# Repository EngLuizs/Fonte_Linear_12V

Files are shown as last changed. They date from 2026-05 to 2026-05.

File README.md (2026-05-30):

# FONTE LINEAR AJUSTÁVEL 12V 1A COM MONITORAMENTO

Projeto desenvolvido pela equipe **FLM System** utilizando ESP32, KiCad e PlatformIO para controle, monitoramento e interface web de uma fonte linear regulada ajustável.

---

# Descrição do Projeto

O projeto consiste em uma fonte linear ajustável de até 12V e 1A com:

- Monitoramento de tensão, corrente e potência
- Interface Web via ESP32
- Display LCD I2C 20x4
- Medição analógica calibrada
- Indicação visual por LED
- PCB dedicada desenvolvida no KiCad
- Controle e aquisição utilizando ESP32-WROOM-32E

O sistema disponibiliza os dados em tempo real tanto no display LCD quanto em uma página web hospedada diretamente pelo ESP32 em modo Access Point.

---

# Funcionalidades

- Leitura de tensão de saída
- Leitura de corrente utilizando resistor shunt
- Cálculo automático de potência
- Web Server integrado
- Interface Web responsiva
- Calibração de tensão e corrente
- LEDs indicadores de status
- Comunicação I2C com display LCD
- Sistema de proteção visual por sobrecorrente

---

# Hardware Utilizado

## Processador
- ESP32-WROOM-32E

## Reguladores
- LM7812
- LM2576
- LD1117

## Componentes principais
- LM358
- TIP120
- BC547
- LCD I2C 20x4
- Shunt 0.22Ω / 5W 
- Shunt 0,33Ω / 5W

---

# Estrutura do Projeto

```text
Firmware/       -> Código fonte do ESP32
Hardware/            -> Esquemáticos, PCB e Gerbers
Documentação/   -> Relatórios e documentação
Estrutura/      -> Estruturas e peças mecânicas
```

---

# Firmware

O firmware foi desenvolvido utilizando:

- Visual Studio Code
- PlatformIO
- Framework Arduino para ESP32

## Principais bibliotecas

- Arduino.h
- Wire.h
- LiquidCrystal_I2C
- WiFi.h
- WebServer.h

---

# Interface Web

O ESP32 opera em modo Access Point criando a rede:

```text
SSID: FLM_FTE12V
Senha: 11110000
```

Após conexão, o sistema disponibiliza:
- Página web embarcada
- Dados em JSON
- Monitoramento em tempo real

---

# Monitoramento

O sistema realiza:

- Média de amostras ADC
- Filtragem sincronizada em 60Hz
- Correção de offset
- Calibração linear de tensão e corrente

---

# PCB e Projeto Eletrônico

O projeto eletrônico foi desenvolvido no:

- KiCad

Incluindo:
- Esquemático completo
- PCB dedicada
- Gerbers de fabricação
- Instrumentação analógica
- Fonte linear regulada
- Conversores DC-DC auxiliares

---

# Organização de Versionamento

Este projeto utiliza:

- Git
- GitHub

Para:
- Controle de revisões
- Histórico de alterações
- Backup
- Versionamento de firmware e PCB

---

# Equipe

FLM System

---

# Versão Atual

```text
Versão Firmware: 0.02.01
Última Revisão: 01/05/2026
```

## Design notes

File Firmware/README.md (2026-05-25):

# 💻 Firmware - Fonte Linear Ajustável (FLM System)

Este diretório contém o código-fonte integral do microcontrolador **ESP32**, responsável pelo sistema de instrumentação inteligente, processamento digital de sinais (DSP) e telemetria remota da Fonte Linear Ajustável (12V / 1A).

O desenvolvimento foi realizado em **C++**, com gerenciamento de dependências e compilação otimizada pelo **PlatformIO** no ambiente Visual Studio Code.

---

## 🗂️ Arquitetura do Software

A arquitetura foi projetada para otimizar o uso da memória SRAM do microcontrolador, isolando a lógica de controle pesada da interface gráfica:

* 📄 **`main.cpp`**: O núcleo de controle. Gerencia periféricos (I2C, ADC, Wi-Fi), executa o ciclo de DSP, calibra as leituras e responde aos *endpoints* da API REST.
* 📄 **`html.h`**: Armazena o *front-end* completo (HTML, CSS e JavaScript Vanilla) diretamente na memória de programa do chip (`PROGMEM`), liberando a RAM para o processamento de rede.
* 📄 **`images.h` e `images.cpp`**: Recursos visuais convertidos em matrizes de bytes binários (*hex arrays*), evitando a necessidade de um sistema de arquivos (SPIFFS/LittleFS).

---

## 🧠 Processamento Digital de Sinais (DSP) e Calibração

O grande diferencial deste firmware é atuar como um instrumento de precisão, não confiando cegamente nas leituras brutas do ADC. Foram implementadas quatro camadas de tratamento matemático:

### 1. Filtro Passa-Baixa (Rejeição de 60Hz)
Para mitigar o ruído eletromagnético (EMI) e a oscilação (*ripple*) da fonte AC, a função `lerMedia()` coleta 60 amostras do ADC com um atraso cirúrgico de 277µs entre cada leitura. 
O tempo total de amostragem ($60 \times 277\mu s$) resulta em aproximadamente **16,6 milissegundos** — o equivalente exato a um ciclo completo da rede elétrica de 60Hz. Isso promove o cancelamento natural das harmônicas da rede.

### 2. Auto-Tara de Ruído Basal (Offset)
Amplificadores Operacionais possuem tensões de deslocamento intrínsecas. Durante o *boot*, o algoritmo executa `medirOffset()`, aferindo 200 amostras do canal de corrente com a fonte em repouso. Esse viés de hardware é armazenado e subtraído de todas as leituras futuras, garantindo que o zero absoluto seja real.

### 3. Regressão Linear de 2 Pontos
A não-linearidade do ADC do ESP32 foi corrigida via software aplicando a equação da reta ($y = ax + b$). O código compara tensões e correntes reais medidas por um instrumento de referência com as leituras brutas do ADC, calculando os coeficientes dinamicamente para gerar uma leitura perfeitamente calibrada.

### 4. Compensação de Carga (Voltage Drop)
Como o resistor *shunt* (0,22 Ω) está em série com o retorno (GND), ele gera uma queda de tensão que mascararia o valor entregue à carga. O firmware calcula ativamente a tensão dissipada pelo próprio *shunt* e a subtrai da medição global da fonte (`tensaoAtual = tensao - Vshunt_real`), exibindo apenas a tensão útil e real.

### 5. Supressão de Zona Morta (Zero Blanking)
Ruídos térmicos residuais que representem medições fantasmas inferiores a **90mA** são logicamente forçados a `0.000 A`, garantindo total estabilidade do display em momentos de circuito aberto.

---

## 📡 Servidor Web e Interface Gráfica

O ESP32 atua de forma autônoma como um *Soft Access Point* (SoftAP), gerando sua própria rede Wi-Fi (`SSID: FLM_FTE12V`). O roteamento foi desenhado no padrão REST:

* **`GET /`** : Transmite o Dashboard (Dashboard responsivo e sem recarregamento de página).
* **`GET /dados`** : Endpoint de telemetria. Retorna um **JSON** com as grandezas filtradas em tempo real. Exemplo:
  ```json
  {"v": 12.05, "i": 0.850, "p": 10.24}

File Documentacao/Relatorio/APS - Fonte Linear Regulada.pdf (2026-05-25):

UNIVERSIDADE PAULISTA CAMPUS RIBEIRÃO PRETO

ENGENHARIA ELÉTRICA (ELETRÔNICA)

Fonte Linear Regulada com Monitoramento Digital

Grupo: FLM System

Aluno: Luiz Henrique Luz Santos RA: F35CBF8

Aluno: Maycon Matheus Belchior da Silva RA: H7532E8

Aluno: Felipe de Oliveira Canjerano RA: G891988

Aluno: Marcos Vinicius Soares RA: F35CBA7

Aluno: Luís Gustavo Novaes R. Zanini RA: R9519I0

RIBEIRÃO PRETO

2026

LUIZ HENRIQUE LUZ SANTOS

FELIPE DE OLIVEIRA CANJERANO

MARCOS VINICIUS SOARES

MAYCON MATHEUS BELCHIOR DA SILVA

LUIS GUSTAVO NOVAES R

“FONTE LINEAR REGULADA COM MONITORAMENTO DIGITAL” 42A4 - APS - ATIVIDADES PRÁTICAS SUPERVISIONADAS

Aprovado(a) em: ______/______/______

BANCA EXAMINADORA

_________________________________

Prof. Matheus Kotaki

Universidade Paulista - UNIP

RIBEIRÃO PRETO

2026

RESUMO

Este relatório apresenta o desenvolvimento da Atividade Prática Supervisionada

(APS) da Engenharia Elétrica (Eletrônica) no primeiro semestre letivo de 2026. O

objetivo principal do trabalho consiste na construção de uma fonte de alimentação linear

12 volts ajustável e na realização de testes experimentais no projeto. Essa atividade tem

o intuito de colaborar diretamente no aprendizado do curso integrando realizações

práticas com o conhecimento teórico apresentado ao longo do quinto semestre do curso.

Nas seguintes etapas, o relatório apresenta seções importantes que ajudam na

compreensão e validação do trabalho, como a fundamentação teórica dos conceitos

principais do projeto, método de construção adotado, materiais utilizados, cálculos

teóricos e comparações com valores medidos, confirmação do objetivo do projeto, uma

conclusão do trabalho detalhando as dificuldades e opiniões obtidas pelo grupo e uma

série de testes essenciais para validar o funcionamento e garantir a segurança na utilização

da fonte linear.

ABSTRACT

This report presents the development of the Supervised Practical Activity (APS)

in Electrical Engineering (Electronics) during the first semester of 2026. The main

objective of the work is to construct a 12 volt adjustable linear power supply and to carry

out experimental tests of the project. This activity aims to contribute directly to the

learning process of the discipline, integrating practical achievements with the theoretical

knowledge presented throughout the fifth semester. In the following stages, the report

presents important sections that aid in the understanding and validation of the work, such

as the theoretical foundation of the main concepts of the project, the construction method

adopted, the materials used, the theoretical calculations and comparisons with measured

values, the confirmation of the project's objective, a conclusion detailing the difficulties

and opinions obtained by the group, and a series of essential tests to validate the operation

and ensure the safety in the use of the linear power supply.

## Sumário

## Tabelas

Tabela 1 - Comparação das medições de tensão | 30

## Equações

Equação 1 – Tensão de ondulação na entrada do regulador | 23
Equação 2 – Corrente no diodo Zener | 23
Equação 3 – Potência dissipada no resistor | 23
Equação 4 – Tensão máxima na saída | 23
Equação 5 – Resistencia no resistor de proteção | 23
Equação 6 – Limite da corrente para proteção do circuito | 23
Equação 7 – Resistencia no resistor de leitura da corrente de referência | 23
Equação 8 – Leitura da tensão correlacionada a corrente de referência | 24
Equação 9 – Potência dissipada (LM7812) | 24
Equação 10 – Ondulação de corrente no indutor (LM2576) | 24
Equação 11 – Valor da corrente de pico no indutor | 24
Equação 12 – Potência dissipada (LD1117) | 24
Equação 13 – Divisor de tensão para leitura de tensão através do ESP32 | 24
Equação 14 – Leitura da tensão no ESP32 | 24
Equação 15 – Realimentação no U2A | 24
Equação 16 – Ganho de tensão no U2A | 24
Equação 17 – Sinal final da corrente no U2A | 24
Equação 18 – Corrente no LED vermelho | 25
Equação 19 – Corrente no LED verde | 25
Equação 20 - Erro do sistema de proteção da fonte | 33

## Figuras

### 1 Introdução

Uma fonte de tensão ajustável é um equipamento muito utilizado na área eletrônica, em

trabalho, cursos e graduações. A fonte é um objeto que, quando energizado em 127/220 V, pode

transformar essa energia de alternada para contínua. Sua funcionalidade consiste em energizar

circuitos através de pontas de prova conectadas.

Geralmente as pessoas que precisam utilizar a fonte de tensão, apenas conectam ela em

alguma tomada qualquer, fazem ajustes na tensão de saída necessária e a utilizam, porém, é

importante para seus usuários que entendam como ela funciona.

O que há dentro de uma fonte de tensão ajustável? Como funciona o sistema dentro de

uma fonte? Quais circuitos são necessários para gerar uma tensão contínua na saída da fonte?

Essas perguntas podem ser respondidas criando a sua própria fonte de tensão ajustável.

A Atividade Prática Supervisionada do quinto semestre do curso Engenharia Elétrica

(Eletrônica) da UNIP, consiste em realizar a montagem de uma fonte de tensão ajustável

completa, com a ideia de ajudar os alunos a entender como funciona o equipamento que é muito

utilizado pelos próprios estudantes.

### 1.1 Objetivo

O projeto consiste em realizar a montagem de uma fonte de tensão linear ajustável. Essa

fonte precisa de uma tensão de saída ajustável de 0 ~ 12 V ou mais, uma corrente máxima maior

ou igual a 1 A, alimentação a partir da rede elétrica e uma saída estabilizada. Alguns requisitos

também são obrigatórios, como o uso de um retificador de diodos, capacitor de filtragem,

referência de tensão, transistores na função de regulador, ajuste manual da tensão de saída

através de potenciômetros e o circuito deve permitir o controle contínuo, operação em regime

linear e estabilidade sob cargas.

Além desses requisitos, uma etapa importante que os alunos devem se atentar é a

proteção contra sobrecorrentes, o grupo deve usar componentes discretos como o resistor shunt,

justificar seu funcionamento e demonstrar a atuação na prática, além de que o monitoramento

da fonte deve ser digital através de um microcontrolador de forma coerente e que não

comprometa o funcionamento da fonte.

Após a montagem da fonte, os alunos têm como objetivo realizar testes no

funcionamento da fonte como a regulamentação de tensão, variação de carga, comparação de medição e testes na sobrecarga, e também realizar um relatório técnico explicando o passo a

passo da construção do projeto.

### 2 Fundamentação Teórica

### 2.1 Retificação e Filtragem

Para a realização da retificação e filtragem precisamos entender o conceito de diodos e

capacitores.

De acordo com o livro “Dispositivos eletrônicos e teoria dos circuitos” de Robert L.

Boylestad e Louis Nashelsky (BOYLESTAD E NASHELSKY), os diodos são semicondutores

com a funcionalidade de conduzir corrente em somente um sentido e agir como um circuito

aberto para qualquer tentativa de estabelecer corrente no sentido oposto.

Os diodos são feitos de silício e germânio e possuem dois terminais, o ânodo e o cátodo.

Quando o ânodo é energizado na tensão positiva, e o cátodo no negativo, obtemos a polarização

direta, nessa polarização o diodo trabalha conduzindo a carga no circuito e recebe uma queda

de tensão de 0,7 V para os diodos de silício, que são os mais comuns.

Quando o diodo é polarizado inversamente da polarização direta, obtemos a polarização

reversa, o diodo trabalha como um circuito aberto, pois não conduz carga no circuito.

Segundo o livro “Análise de Circuitos Elétricos com aplicações” de Matthew N. O.

Sadiku, Sarhan M. Musa e Charles K. Alexander (SADIKU, MUSA E ALEXANDER), os

capacitores são componentes eletrônicos que armazenam energia para que seja recuperada em

um momento posterior. Esse componente se opõe à variação de tensão, bloqueia passagem de

corrente elétrica contínua e armazena energia, se comportando como um filtro de tensão, e

possuem dielétricos de cerâmica, mica, poliéster, papel ou ar.

Circuitos retificadores são circuitos eletrônicos que convertem corrente alternada para

corrente contínua através de uma combinação de diodos. O mais eficiente é o circuito retificador

de onda completa, utilizando uma ponte de quatro diodos, dois diodos da ponte conduzem por

vez, aproveitando o semiciclo positivo e negativo da onda, gerando mais estabilidade da onda

na saída do circuito.

O capacitor serve para filtrar a tensão que sai do circuito, ele se enche até o pico e

descarrega de forma suave na carga do circuito, fazendo a tensão de saída ter poucas oscilações.

### 2.2 Regulação Linear

Para a realização da Regulação linear precisamos entender o conceito de diodo Zener e

Transistor na configuração Coletor-Comum.

Diferentemente de um diodo comum, o diodo Zener trabalha polarizado inversamente.

Quando polarizado diretamente, ele trabalha como um diodo comum, porém, quando

polarizado reversamente, mantém uma tensão constante de acordo com sua tensão de ruptura.

Para ativar o diodo Zener, a tensão no cátodo do diodo precisa atingir a tensão de ruptura

do componente, após atingir a tensão de ruptura do diodo, qualquer oscilação ou variação de

tensão que passar por ele não alterará na tensão de saída, pois sua função consiste em manter

uma tensão fixa nos terminais. O diodo Zener é muito utilizado em circuitos reguladores para

manter uma tensão fixa, utilizando também um resistor de carga.

De acordo com Boylestad e Nashelsky, o transistor é um dispositivo de silício

semicondutor que consiste em duas camadas de material do tipo N e uma do tipo P ou vice

versa. Sua função consiste em amplificar ou controlar o fluxo da corrente em um circuito, este

dispositivo possui três terminais: base, coletor e emissor.

O transistor na configuração Coletor-Comum possui alto valor de impedância de entrada

e baixo valor de impedância de saída, sendo assim, na região ativa esse componente trabalha

como um regulador, variando a impedância dentro do próprio componente. Essa configuração

de transistor consegue manter a tensão de saída proporcional à tensão de entrada (base) do

componente.

O circuito regulador linear utiliza do transistor e diodo Zener para estabilizar a carga

que vem do circuito retificador. A tensão da base do transistor é estabilizada pelo diodo Zener

e ajustada através de um potenciômetro ou divisor de tensão, estabilizando e controlando toda

a tensão de saída. Desse modo, o diodo Zener fixa um valor constante para tensão da base,

através do potenciômetro ou divisor a tensão se torna ajustável, a tensão entra na base do

transistor, e na configuração coletor-comum, o transistor trabalha como uma resistência

flexível.

### 2.3 Proteção Contra Sobrecorrente

Na realização de um circuito de proteção contra sobrecorrente, precisamos entender o

conceito do Resistor Shunt e sobre o Transistor como chave.

O resistor Shunt é um resistor com baixa resistência utilizado para medir correntes em

circuitos e proteger circuitos juntamente com um transistor como chave. Por ter baixa resistência, a queda de tensão nesse resistor é proporcional a corrente do circuito, vemos através

da lei de ohm (V = R x I).

Já o transistor como chave atua de uma forma um pouco diferente. Os transistores como

chave trabalham em duas regiões, a de corte e saturação. O transistor fica na região de corte

quando não circula corrente na base, bloqueando toda a circulação de carga que passar por ele,

na região de saturação o transistor circula corrente em sua base, permitindo que a corrente que

circula do coletor para o emissor flua normalmente. Dessa forma, o transistor como chave atua

como um interruptor que ativa e desativa a circulação de corrente no circuito para proteger.

O circuito de proteção contra sobrecorrente consiste em manter o resistor Shunt em série

com a saída do circuito e conectada na base do transistor como chave. Quando a corrente está

abaixo do limite permitido e estipulado pelo circuito, o transistor permanece na região de corte

(desligado) pois não há corrente circulando em sua base. Quando a corrente ultrapassa o limite

estipulado, a queda de tensão no resistor Shunt aumenta, fazendo assim o transistor entrar na

região de saturação (ligado). Quando o transistor como chave está saturado, a corrente

indesejada é desviada protegendo o circuito completo.

### 2.4 Sistema Microcontrolado

Sistemas microcontrolados integram memorias, processadores, entradas e saídas em um

circuito integrado. Para a fonte linear ajustável, foi utilizado o microcontrolador ESP32, um

componente de 32 bits dual-core.

O ESP32 é um pouco diferente dos outros microcontroladores de oito bits, pois opera

com frequências altas e possui conectividade wireless. Para a realização de montagem de fontes

de bancada, o ESP32 geralmente é o mais escolhido pela sua quantidade de pinos de

entrada/saída e pela especialização na conversão de sinais analógicos em digital.

Neste projeto, existem valores que são sinais analógicos, como a tensão sobre a carga,

por isso, é necessário a digitalização desses sinais para que o processor interno do ESP32

consiga interpretá-los, função realizada pelo ADC. O Conversor Analógico Digital trabalha em

três etapas: Na amostragem, o ADC captura os valores analógicos. Na quantização, ele mapeia

o valor analógico em um nível de tensão que corresponde a uma escala determinada pela

resolução do circuito. E na codificação, ele converte o sinal em uma palavra binaria que é lida

pelo firmware.

Um dos problemas do microcontrolador são as restrições nas entradas que só suportam

no máximo 3,3 V, sinal de alta potência não pode ser conectado ao microcontrolador. Esse problema é resolvido com os Amplificadores Operacionais, esses amplificadores são circuitos

integrados analógicos com alto ganho nas entradas.

Para exibir as variáveis medidas sem muitos pinos do microcontrolador, é importante

adotar o protocolo de comunicação I2C, esse protocolo da Philips utiliza uma topologia baseada

em apenas dois condutores ativos. Serial Data é a linha responsável pela transferência serial de

dados nos dispositivos e o Serial Clock é responsável pelo sinal que gera sincronismo nos

dispositivos (VICTOR VISION, 2022).

### 3 Materiais e Métodos

### 3.1 Projeto do Circuito

O projeto elétrico foi concebido sob uma topologia híbrida, integrando um estágio

analógico robusto, dedicado à regulação linear de potência, e um estágio digital de precisão,

responsável pela telemetria e conectividade. O escopo principal do projeto é garantir o

fornecimento de uma tensão contínua ajustável de 0 a 12V com capacidade de corrente de até

1A, mantendo a estabilidade da tensão de saída e a proteção ativa do hardware contra falhas na

carga.

Para otimizar o desenvolvimento, isolar ruídos e facilitar a análise de falhas, a

arquitetura do hardware foi dividida em cinco módulos funcionais inter-relacionados:

Módulo de Retificação e Filtragem: Responsável por receber a tensão alternada (AC)

proveniente do transformador, realizar a retificação em onda completa através de uma ponte de

diodos e atenuar a oscilação (Ripple) utilizando um banco de capacitores eletrolíticos de alta

capacitância, entregando o barramento DC principal (+18V) ao sistema.

Módulo de Regulação e Potência: O núcleo de controle analógico da fonte. Utiliza a

configuração Darlington para modular a tensão de saída conforme o ajuste do usuário no

potenciômetro e o referencial do diodo Zener.

Módulo de Proteção Ativa: Circuito de segurança em malha fechada composto por

resistores de limitação e um transistor. Este bloco atua drenando a corrente de base do transistor

de potência caso a corrente total do sistema ultrapasse o limite seguro de projeto, cortando a

saída imediatamente.

Módulo de Instrumentação Analógica: Estágio de condicionamento de sinal. Utiliza

divisores de tensão resistivos e um resistor Shunt no caminho de retorno (GND). As quedas de

tensão geradas são tratadas por Amplificadores Operacionais, adequando as altas tensões da

fonte para os níveis lógicos seguros de leitura do microcontrolador (0 a 1.1V).

Módulo de Processamento e Conectividade: Centrado no microcontrolador ESP32.

Este bloco opera de forma passiva em relação à potência da fonte, realizando a conversão

analógico-digital (ADC) dos sinais de instrumentação, o tratamento matemático via software e

a disponibilização dos dados no display LCD e no Servidor Web Wi-Fi.

Esta modularização garante que a lógica de controle digital opere de maneira segura,

minimizando interferências provenientes do chaveamento e do calor gerado pelas cargas de alta

potência.

### 3.2 Montagem Experimental

Após inúmeras reuniões e apresentações de ideias entre o grupo, a fonte finalmente tinha

um começo no digital, com auxílio do Software KiCad foi desenvolvida uma primeira amostra

de um esquemático da possível fonte. Com todos os testes, análises, modificações e quase

certeza que o projeto estava apto, a realização da criação da PCB da fonte foi iniciada.

A confecção da Placa de Circuito Impresso (PCB) de dupla face foi realizada em etapas

sequenciais, unindo usinagem, transferência térmica e processos fotoquímicos. O fluxo de

fabricação seguiu as seguintes fases:

- Usinagem e Transferência de Layout: Inicialmente, a placa de fenolite foi

dimensionada e cortada com o auxílio de uma fresadora CNC (Figura 1). Em seguida,

o layout do circuito foi aplicado de forma alinhada nas faces inferior (Bottom Layer) e

superior (Top Layer) através do método de transferência térmica (Figuras 2 e 3).

- Corrosão Química: Para a remoção do cobre não utilizado, a placa foi submetida a um

banho químico utilizando percloreto de ferro (Figura 4). Esse processo garantiu o

isolamento perfeito das trilhas protegidas pelo polímero do toner, resultando nas

camadas limpas e corroídas (Figuras 5 e 6).

- Aplicação da Máscara de Solda (Solder Mask): Após a limpeza, a PCB recebeu a

aplicação de uma tinta fotossensível protetora (Figura 7). Para garantir que apenas as

ilhas de soldagem (pads) ficassem expostas, utilizou-se um fotolito impresso em papel

transparente alinhado milimetricamente sobre a placa (Figura 8). A secagem e

polimerização da resina foram realizadas mediante exposição controlada à luz

ultravioleta (UV) durante um tempo de aproximadamente 5 à 10 minutos (Figura 9),

finalizando o processo de cura em ambas as faces (Figuras 10 e 11).

- Acabamento Final: O uso da máscara UV teve como objetivo proteger as trilhas de

cobre contra a oxidação natural, prevenir curtos-circuitos acidentais durante a futura

fixação dos componentes com estanho e conferir um acabamento estético e profissional

às faces inferior e superior da placa finalizada (Figuras 12 e 13).

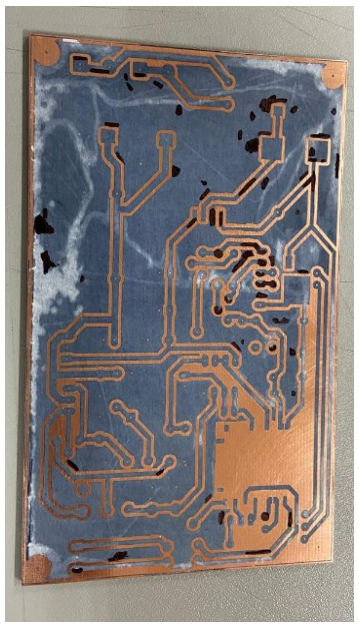
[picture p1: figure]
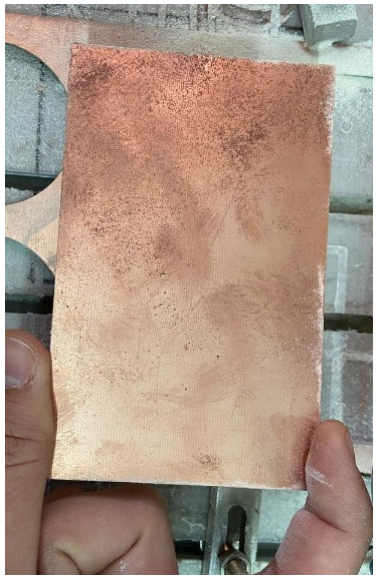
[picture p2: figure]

Figura 1 – Corte da placa fenolite na Fresa CNC. Figura 2 – Transferência térmica do Bottom Layer.

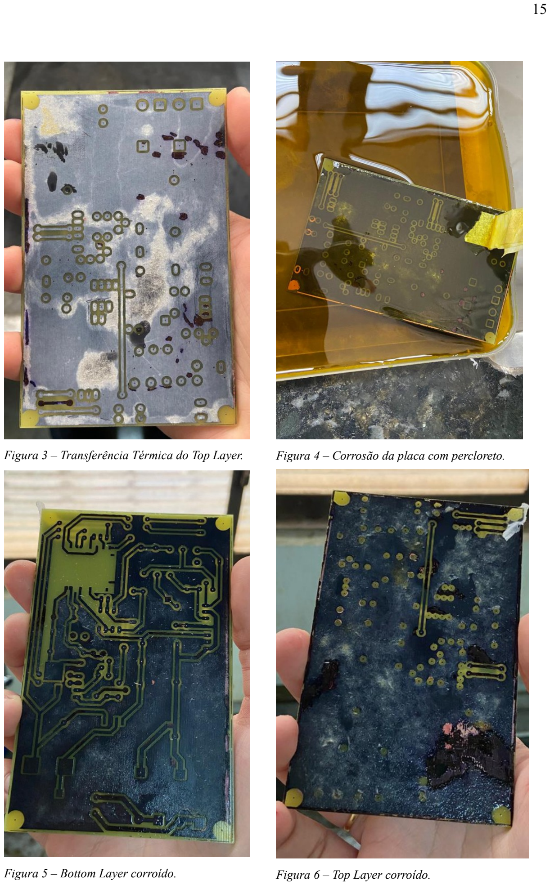
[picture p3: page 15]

Figura 3 – Transferência Térmica do Top Layer. | Figura 4 – Corrosão da placa com percloreto.
Figura 5 – Bottom Layer corroído. | Figura 6 – Top Layer corroído.

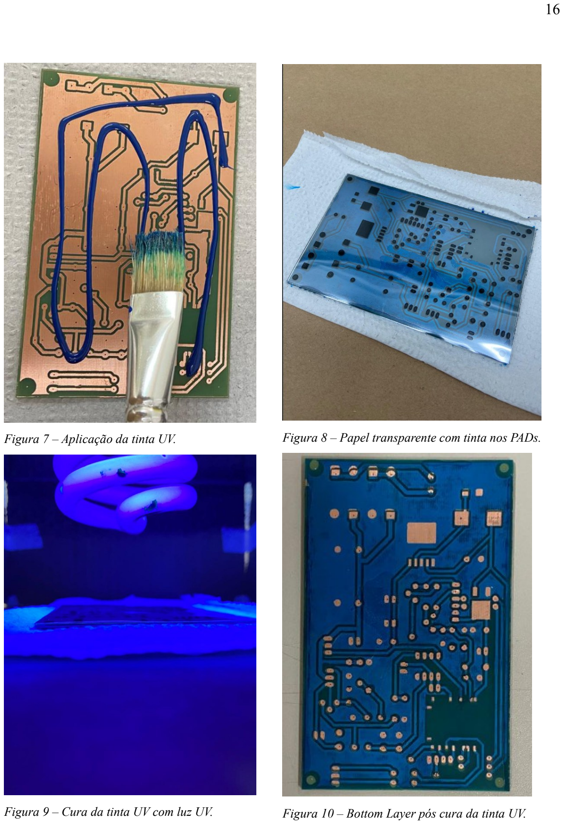
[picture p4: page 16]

Figura 7 – Aplicação da tinta UV. | Figura 8 – Papel transparente com tinta nos PADs.
Figura 9 – Cura da tinta UV com luz UV. | Figura 10 – Bottom Layer pós cura da tinta UV.

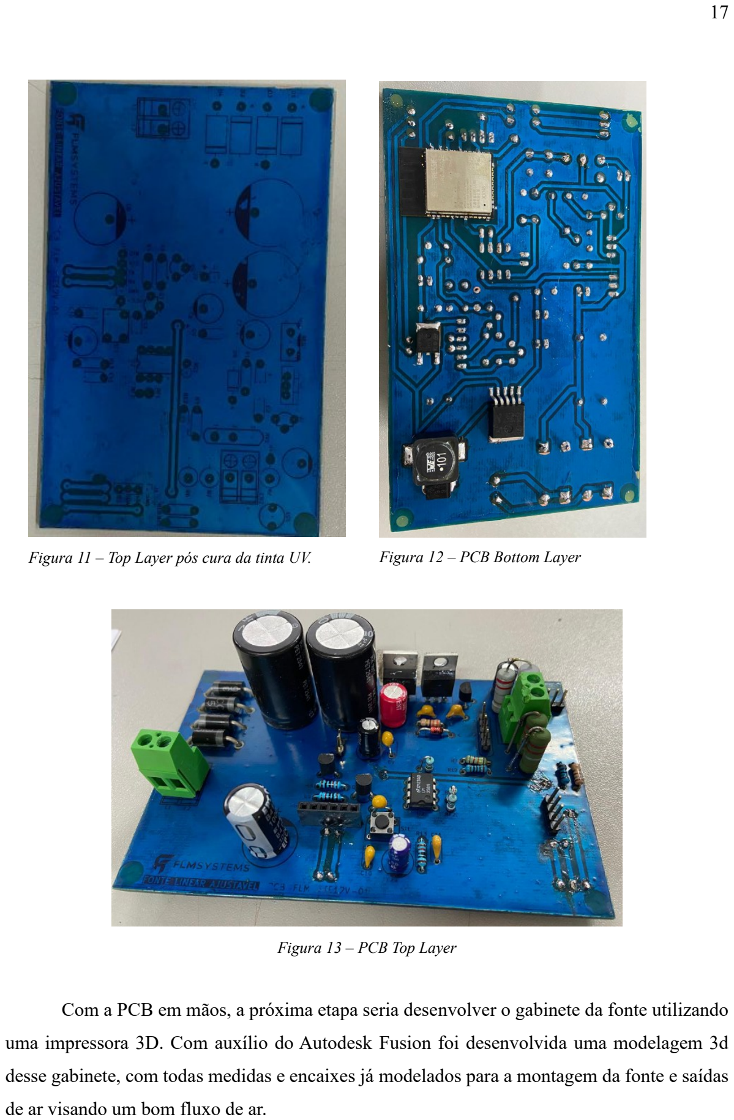
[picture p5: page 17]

Figura 11 – Top Layer pós cura da tinta UV. | Figura 12 – PCB Bottom Layer

Figura 13 – PCB Top Layer

Com a PCB em mãos, a próxima etapa seria desenvolver o gabinete da fonte utilizando

uma impressora 3D. Com auxílio do Autodesk Fusion foi desenvolvida uma modelagem 3d

desse gabinete, com todas medidas e encaixes já modelados para a montagem da fonte e saídas

de ar visando um bom fluxo de ar.

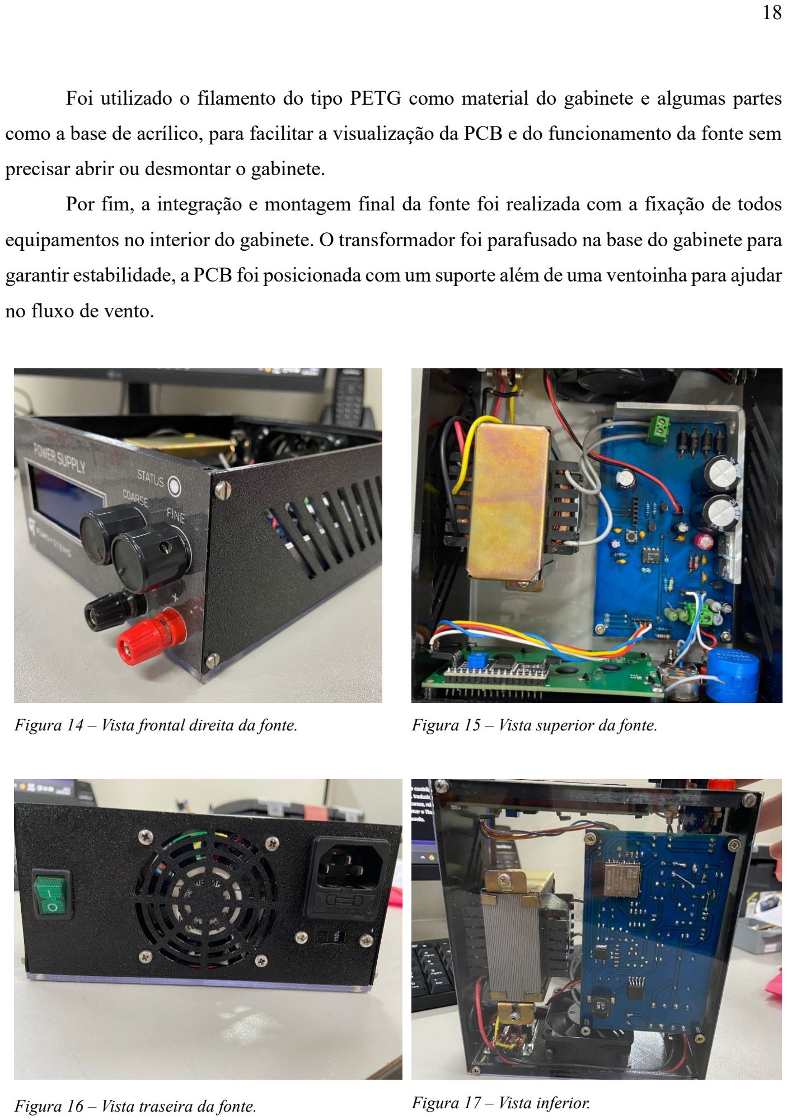
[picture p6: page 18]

Foi utilizado o filamento do tipo PETG como material do gabinete e algumas partes

como a base de acrílico, para facilitar a visualização da PCB e do funcionamento da fonte sem

precisar abrir ou desmontar o gabinete.

Por fim, a integração e montagem final da fonte foi realizada com a fixação de todos

equipamentos no interior do gabinete. O transformador foi parafusado na base do gabinete para

garantir estabilidade, a PCB foi posicionada com um suporte além de uma ventoinha para ajudar

no fluxo de vento.

Figura 14 – Vista frontal direita da fonte. | Figura 15 – Vista superior da fonte.
Figura 16 – Vista traseira da fonte. | Figura 17 – Vista inferior.

### 3.3 Esquemático

O diagrama esquemático representa a modelagem lógica e elétrica global da fonte linear

ajustável, mapeando as interconexões fundamentais entre os blocos de potência, regulação,

segurança e o sistema microcontrolado baseado no ESP32. Este documento técnico estabelece

a topologia exata das trilhas, barramentos de comunicação (I2C), redes de distribuição de tensão

(+18V, +12V, +5V, +3.3V) e o correto acoplamento dos componentes discretos e circuitos

integrados.

Para assegurar o rigor técnico e preservar a perfeita legibilidade das trilhas, pinagens e

identificadores (designators) de componentes, os quais sofreriam perda de resolução se

reduzidos às margens normativas deste relatório, os diagramas técnicos completos foram

exportados diretamente do software de automação de design eletrônico (KiCad) e

disponibilizados em alta definição.

A documentação oficial de hardware encontra-se indexada e versionada no repositório

público da equipe no GitHub através do endereço eletrônico: PCB - Layout, (https://github.com/EngLuizs/Fonte_Linear_12V/tree/main/PCB/PDF) contendo os

seguintes arquivos:

- FLM-FTE-SCH-01.pdf: Diagrama esquemático completo do circuito, detalhando as

conexões elétricas e pinagens de controle.

- FLM-FTE-PCB-01.pdf: Desenho técnico de posicionamento de componentes e

roteamento das camadas física superior (Top) e inferior (Bottom).

- FLM-FTE-PCB-FAB-01.pdf: Arquivo consolidado com as máscaras de solda, furação

e guias de gabarito para os processos de transferência térmica e fabricação da placa.

- FLM-FTE-PCB-3D-01.pdf: Modelagem tridimensional da placa montada (PCBA),

permitindo a visualização espacial dos componentes, verificação de folgas mecânicas

(clearances) e validação para o encapsulamento no gabinete impresso.

### 3.4 Funcionamento dos componentes

Diodos Retificadores (1N5406) são posicionados em forma de ponte que fazem esses

semicondutores conduzirem corrente em pares durante dois semi-ciclos (positivo e negativo), fazendo assim, a corrente alternada que vem do transformador ser convertida em corrente

contínua.

Capacitores de filtro (4700 µF) atuam como filtro, eles guardam a energia nos pontos

de pico das ondas e descarregam de forma suave reduzindo a oscilação da tensão, entregando

uma tensão mais regular e estável.

Diodo Zener (1N4744A) trabalhando na região de ruptura inversa, esse diodo consegue

fixar a tensão de referência que chega no potenciômetro, independe das oscilações que tiverem

na entrada do circuito, a tensão no diodo Zener não oscila.

Resistor de polarização (330 Ω) serve para limitar a corrente que circula no diodo

Zener, evitando sobreaquecimento ele permite o diodo Zener trabalhar na região ideal com

segurança e polariza o diodo.

Potenciômetro (11k Ω) atua como um divisor de tensão ajustável, ele posicionado em

paralelo com o diodo Zener e conectado na base do transistor de potência, pode ajustar a tensão

de saída da fonte conforme o giro do seu eixo.

Transistor de Potência (TIP120) é o principal regulador do circuito pois oferece um

ganho alto de corrente, ele recebe uma corrente baixa em sua base que serve como controle para

uma corrente maior que vai para a carga.

Transistor de Proteção (BC547) age como uma chave de proteção no circuito, esse

transistor monitora a queda de tensão nos resistores de proteção, quando essa queda passar de

0,7 V ele desvia a corrente de sua base diretamente ao GND, desta forma, protegendo o circuito

de um curto-circuito ou sobrecorrente.

Resistores de Proteção (0,33 Ω; 0,22 Ω) em série na saída da fonte, servem para

converter a corrente da saída em tensão, sendo assim, fazendo o transistor de proteção conseguir

monitorar a segurança do circuito.

Resistores Shunt (0,22 Ω) na linha de retorno conseguem gerar uma queda de tensão

proporcional à corrente consumida no circuito, sendo essencial para o sistema de medição da

fonte.

O capacitor (0,1 µF) serve também como filtro, porém, especificamente para a tensão

de referência no diodo Zener e potenciômetro.

O capacitor (100µF) atua como um filtro focado na estabilidade da fonte, suavizando

as transições que acontece no circuito.

Regulador Linear (LM7812) Recebe 18 V da filtragem do circuito e reduz para 12 V

com sua regulação interna.

Regulador Chaveado (LM2576D2TR4–5G) é um circuito integrado conversor DC–

DC, que no circuito reduz a tensão de 12 V para 5 V ligando e desligando internamente.

Diodo Schottky (SS36) fornece um caminho em que a corrente armazenada no indutor

continue fluindo evitando picos de alta tensão quando o regulador chaveado está fechado.

Indutor (100µH) armazena energia em campo magnético quando o regulador está

fechado e libera a energia quando o regulador abre.

Capacitor (1000µF) junto com o indutor forma um filtro passa–baixas que transforma

a pulsação da onda em uma tensão contínua de 5 V.

Regulador LDO (LD1117DT33TR) tem uma baixa queda de tensão, recebe 5 V estável

e fixa uma saída de 3,3 V para alimentar o microcontrolador.

Capacitores de Desacoplamento (0,1; 100; 0,1; 100; 0,1; 10 µF) filtram os ruídos da

rede ou chaveamento, gerando estabilidade nas entradas e saídas dos circuitos integrados.

Microcontrolador (ESP32) executa o firmware do projeto, realiza todas leituras e

cálculos de monitoramento, gerencia as proteções do circuito e envia todas informações

necessárias para o display.

Amplificadores Operacionais U2B, U2A (LM358N) são circuitos amplificadores, o

U2B isola o divisor de tensão da saída da fonte para garantir a não interferência da leitura com

o valor de saída. Já o U2A multiplica por 4 o sinal do resistor Shunt, transformando esse valor

em legível para o ESP32 conseguir medir a corrente.

Resistores no Divisor de Tensão (14k Ω, 1k Ω) reduzem a tensão máxima para uma

faixa segura que permite a leitura pelo pino analógico do ESP32

Transistores (BC547) funcionam como chaves digitais automáticas comandadas por

sinais digitais que colocam o ESP32 em modo gravação.

O Botão ST1 possibilita resetar o microcontrolador, o resistor 10k Ω mantém o pino reset

em nível alto e o capacitor 0,1 µF elimina os ruídos desse circuito.

LED Bicolor com resistores (180 Ω, 150 Ω) age como indicador visual do status da

fonte, os resistores limitam a corrente dos LEDs.

### 3.4.1 Lista de Materiais (B.O.M. - Bill of Materials)

Com o intuito de garantir a total reprodutibilidade do hardware e documentar de forma

rigorosa todos os insumos utilizados, a Lista de Materiais (B.O.M.) da fonte linear regulada foi

consolidada em uma planilha digital detalhada.

Para manter a clareza e a formatação enxuta deste relatório, o documento completo em

formato Excel (.xlsx) encontra-se hospedado e versionado no repositório público da equipe no

GitHub. A lista de especificações pode ser acessada através do seguinte endereço eletrônico:

Lista de Materiais - B.O.M. (https://github.com/EngLuizs/Fonte_Linear_12V/tree/main/PCB/BOM)

A estrutura da listagem foi desenvolvida em total consonância com o projeto modelado

no software de automação de design eletrônico KiCad. Para cada item listado na planilha, o

avaliador encontrará as seguintes especificações técnicas:

- Designator: A referência unívoca e identificadora do componente no diagrama

esquemático (ex: R1, C1, U1);

- Valor / Modelo: A especificação nominal ou o modelo comercial do componente;
- Footprint (Encapsulamento): O padrão de desenho físico e dimensional adotado para

a furação, posicionamento e soldagem dos terminais na PCB;

- Quantidade (Qtd.): O volume total de unidades necessárias para a montagem de uma

placa.

### 3.5 Cálculos

∆Vripple =

Imax
ℱ × C

Equação 1 – Tensão de ondulação na entrada do regulador

Iz =

Vin − Vz
R1

→

18 V − 15 V
330 Ω

= 9 mA

Equação 2 – Corrente no diodo Zener

Pr =

(Vin − Vz)²
R1

→

(18 V − 15 V)²
330 Ω

= 27 mW

Equação 3 – Potência dissipada no resistor

Vout = Vbase (TIP120) − Vbe (TIP120) → 15 V − 1,4 V = 13,6 V

Equação 4 – Tensão máxima na saída

Rproteção = R2 + R4 → 0,33 Ω + 0,22 Ω = 0,55 Ω

Equação 5 – Resistencia no resistor de proteção

Ilimite =

Vbe (BC547)

Rproteção

→

0,7 V
0,55Ω ≅ 1,27 A

Equação 6 – Limite da corrente para proteção do circuito

Rref = R6 → 0,22 Ω

Equação 7 – Resistencia no resistor de leitura da corrente de referência

Vsℎunt = I × Rref

Equação 8 – Leitura da tensão correlacionada a corrente de referência

Pd

(LM7812) = Vin − Vout × Iout → 18V − 12V × 0,5 A = 3 W

Equação 9 – Potência dissipada (LM7812)

∆Il (LM2576) =

Vin − Vout × Vout
Vin × ℱ × L

→

12 V − 5 V × 5 V
12 V × 52 kHz × 100µH

= 0,56 A

Equação 10 – Ondulação de corrente no indutor (LM2576)

Ipico = Iout +

∆Il
2

→ 1 A +

0,56 A
2

= 1,28 A

Equação 11 – Valor da corrente de pico no indutor

Pd

(LD1117) = Vin − Vout × Iout → 5 V − 3,3 V × 0,2 A = 0,34 W

Equação 12 – Potência dissipada (LD1117)

V(U2B) = Vout ×

R12
R3 + R12

→ 15 V ×

1k Ω
14k Ω + 1k Ω

= 1 V

Equação 13 – Divisor de tensão para leitura de tensão através do ESP32

Ler_V = VU2B

Equação 14 – Leitura da tensão no ESP32

RF = RF1 + RF2 → 15k Ω + 15k Ω = 30k Ω

Equação 15 – Realimentação no U2A

GU2A = 1 +

RF

RG1

→ 1 +

30k Ω
10k Ω

= 4

Equação 16 – Ganho de tensão no U2A

Ler_I = GU2A × Ler_Iref (Icarga × 0,22 Ω) → 4 x 1,1A x 0,22Ω = 0,968 V

Equação 17 – Sinal final da corrente no U2A

ILEDRED =

Vin − VD
R10

→

3,3 V − 2 V
180 Ω

= 7,22 mA

Equação 18 – Corrente no LED vermelho

ILEDgreen =

Vin − VD
R11

→

3,3 V − 2 V
150 Ω

= 8,66 mA

Equação 19 – Corrente no LED verde

### 3.6 Firmware

O firmware do sistema foi integralmente desenvolvido sob o ecossistema de código

aberto utilizando a linguagem C++ integrada ao framework Arduino. Como ambiente de

desenvolvimento (IDE), adotou-se o Visual Studio Code (VS Code) em conjunto com a

extensão PlatformIO. Esta escolha justifica-se pela robustez no gerenciamento de bibliotecas,

compilação otimizada para o processador de arquitetura Xtensa de 32 bits do ESP32 e suporte

avançado a sistemas de versionamento.

A arquitetura do software foi estruturada de forma modular para otimizar o uso de

memória do microcontrolador, dividindo-se em três arquivos principais:

- Código Principal (src/main.cpp): Responsável pelo controle de baixo nível,

inicialização de periféricos, execução dos filtros digitais e gerenciamento das

requisições do servidor.

- Interface Web (include/html.h): Arquivo de cabeçalho que armazena a estrutura do

front-end (HTML, CSS e JavaScript) na memória de programa do chip (PROGMEM),

evitando o consumo da memória RAM (SRAM) dinâmica.

- Recursos Visuais (include/images.h): Armazena as imagens de interface convertidas

em matrizes de bytes binários (hex arrays) para transmissão direta via rede.

### 3.6.1 Bibliotecas e Periféricos

Para a operação integrada dos componentes e protocolos de comunicação, o firmware

incorpora as seguintes bibliotecas nativas e externas:

- Arduino.h: Fornece a API base para controle dos pinos de Entrada/Saída (GPIO) e

temporizadores do chip.

- Wire.h: Gerencia o barramento de comunicação serial síncrona I2C nos pinos

customizados (SDA: GPIO 16, SCL: GPIO 19).

- LiquidCrystal_I2C.h: Controla o display LCD de 20 colunas por 4 linhas,

encapsulando os comandos de escrita e posicionamento de cursor via I2C.

- WiFi.h: Configura o modem de rádio do ESP32 para operar estritamente em modo Soft

Access Point (SoftAP), gerando uma rede local criptografada sem a necessidade de um

roteador externo.

- WebServer.h: Instancia um servidor HTTP escutando na porta padrão 80, encarregado

de processar os métodos de requisição dos clientes conectados.

### 3.6.2 Infraestrutura de Rede e Endpoints HTTP (API JSON)

O ESP32 atua simultaneamente como ponto de acesso Wi-Fi (SSID: "FLM_FTE12V")

e servidor de aplicação. O roteamento de dados do servidor web foi projetado sob o modelo

arquitetural REST, expondo endpoints específicos mapeados por meio de funções lambda:

1. Rota Raiz (/): Quando o usuário acessa o endereço IP da fonte, o servidor dispara uma

resposta HTTP com código de status 200 (OK), transmitindo o documento

INDEX_HTML em formato de texto e hipertexto.

2. Rota de Telemetria (/dados): Este endpoint expõe os dados brutos da fonte em tempo

real. Ele encapsula as variáveis globais de medição dinamicamente e as envia

formatadas como uma string em padrão JSON (JavaScript Object Notation), conforme

a estrutura abaixo:

JSON

{"v": 12.00, "i": 0.500, "p": 6.00}

3. Rotas de Mídia (/logo.png e /fonte.png): Enviam os dados binários das imagens com

o cabeçalho (MIME type) definido como image/png, permitindo que o navegador

renderize o layout visual completo da FLM Systems.

### 3.6.3 Interface Gráfica e Comunicação Assíncrona (Front-end)

A interface de monitoramento remoto foi desenvolvida utilizando HTML5 estrutural,

folhas de estilo CSS3 responsivas (adaptáveis a telas de computadores e smartphones) e scripts

interpretados em JavaScript puro (Vanilla JS).

O mecanismo de atualização da tela dispensa o recarregamento completo da página web,

técnica que saturaria o poder de processamento do ESP32. Em vez disso, o navegador executa

um loop assíncrono baseado na função setInterval() a cada 1000 milissegundos. Esse loop

realiza uma requisição de segundo plano via objeto XMLHttpRequest (padrão AJAX) voltada

ao endpoint /dados.

Ao receber o objeto JSON com a telemetria, o motor JavaScript decodifica os valores e

atualiza imediatamente os elementos de texto do painel. Simultaneamente, o script insere esses

dados em vetores de histórico (arrays FIFO com limite de 40 pontos) e realiza a renderização

vetorial de gráficos de linha em tempo real utilizando de forma direta a API gráfica do elemento

nativo HTML (canvas), desenhando curvas dinâmicas de comportamento para Tensão, Corrente

e Potência.

O código-fonte completo deste firmware, estruturado para o ambiente PlatformIO,

encontra-se hospedado no repositório público da equipe através do seguinte endereço

eletrônico: Firmware - Fonte Linear 12V - Github. (https://github.com/EngLuizs/Fonte_Linear_12V/tree/main/Firmware)

### 3.7 Algoritmo e Processamento de Sinais

O algoritmo embarcado no ESP32 foi desenvolvido para ir além da simples leitura de

conversores analógico-digitais (ADCs). Ele atua como uma camada de instrumentação

inteligente, aplicando técnicas de Processamento Digital de Sinais (DSP) e compensações

matemáticas para garantir a precisão das grandezas elétricas exibidas. O ciclo de execução

principal pode ser visualizado na Figura 18.

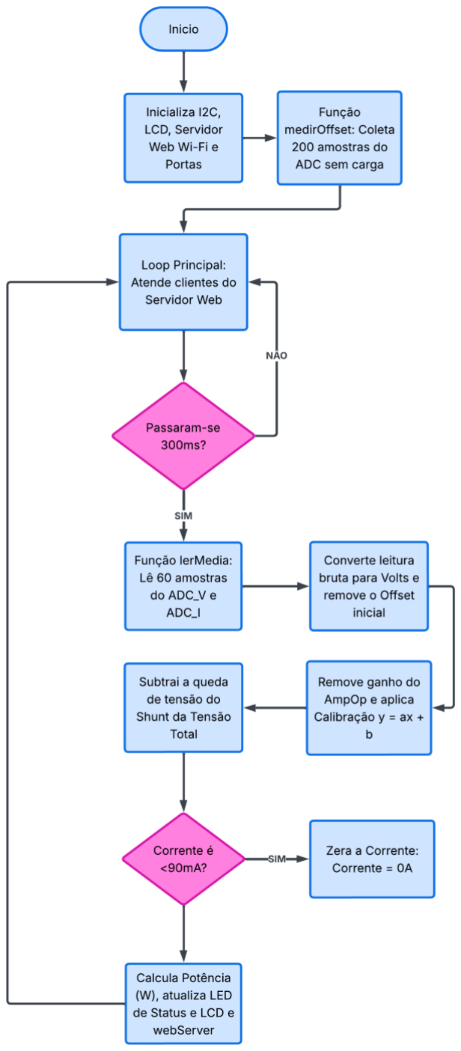
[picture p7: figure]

Figura 18 – Fluxograma de processamento e controle do firmware.
(Fonte: Autoria própria, 2026)

### 3.7.1 Filtragem e tratamento de Ruído (DSP)

Para suavizar a flutuação de leitura causada pelo Ripple da fonte de alimentação e por

interferências eletromagnéticas (EMI), o firmware não utiliza leituras instantâneas do ADC. Foi

implementada a função lerMedia(), que atua como um filtro passa-baixa digital por Média

Móvel. O algoritmo coleta 60 amostras, introduzindo um atraso de 277 microssegundos entre

cada leitura. A soma desse tempo (60 x 277µs ≈ 16,6ms) equivale exatamente a um ciclo

completo da rede elétrica de 60Hz, promovendo o cancelamento natural de ruídos harmônicos

da rede antes mesmo do cálculo matemático.

### 3.7.2 Auto calibração de Zero (Offset)

Amplificadores operacionais, como o LM358N utilizado no circuito, possuem tensões

de deslocamento intrínsecas (Input Offset Voltage). Para evitar que a fonte registre consumo de

corrente com os bornes vazios, o algoritmo executa a rotina medirOffset() durante a

inicialização (Setup). Essa função afere o ruído basal do hardware sem carga conectada e

armazena esse valor, funcionando como a função "Tara" de uma balança analítica, subtraindo

esse viés de todas as leituras subsequentes.

### 3.7.3 Regressão Linear e Compensação de Carga

As não-linearidades dos componentes eletrônicos e do ADC do ESP32 são corrigidas

via software utilizando uma equação de calibração de dois pontos (Regressão Linear Simples:

y = ax = b). Após aplicar o fator de calibração, o algoritmo soluciona o problema físico da queda

de tensão (Voltage Drop) no resistor shunt.

Como o resistor shunt encontra-se em série com o referencial negativo da carga, o

algoritmo calcula a tensão dissipada pelo próprio resistor (Vshunt_real) e a subtrai ativamente

da tensão total medida pelo divisor resistivo (tensaoAtual = tensao - Vshunt_real). Isso garante

que o valor exibido no display e na página Web seja rigorosamente a tensão útil entregue aos

bornes de saída.

### 3.7.4 Supressão de Zona Morta (Zero Blanking)

Para garantir estabilidade visual e confiabilidade em níveis de instrumentação, o

firmware incorpora uma lógica de supressão de ruído térmico em baixas correntes, conhecida

como Zero Blanking. Qualquer leitura flutuante processada pelo ADC que represente uma

corrente inferior a 90mA é forçada logicamente a 0A (if (correnteAtual < 0.090)), garantindo

que o display permaneça limpo e cravado quando a fonte estiver inoperante.

### 4 Resultados Experimentais

### 4.1 Testes de regulação, variação e comparação

Os testes experimentais da fonte foram feitos com o auxílio da carga eletrônica de

corrente contínua BK PRECISION 8540 e do multímetro Minipa ET-1110B. Com ajustes nestes

equipamentos e na própria fonte do projeto, foi possível observar a regulação de tensão com

pelo menos três valores distintos de tensão para análise e verificar a estabilidade de tensão em

todos os ajustes feitos na fonte.

Também foram feitas alterações nos valores da carga de teste para analisar como a fonte

se comportaria em cada ocasião, a variação de carga foi dividida em cinco níveis de carga,

sendo eles: 0 A; 0,1 A; 0,25 A; 0,5 A; 0,75 A; 1 A.

Uma comparação de tensão foi feita para verificar a porcentagem de erro e precisão da

fonte. Na Tabela 1, foram anotados todos os valores medidos nos testes e a porcentagem de erro

da fonte, e nas Figuras X foram registradas fotografias como comprovação do momento exato

que foi realizado cada etapa dos testes.

Tabela 1 - Comparação das medições de tensão

Tensão
Ajustada (V)

Corente
Aplicada (A)

Tensão
Multímetro (V)

Tensão
Display (V)

Erro
Absoluto (V)

Erro Relativo
(%)
12,00 | 0,000 | 12,05 | 11,99 | 0,06 | 0,50%
| 0,100 | 11,48 | 11,45 | 0,03 | 0,26%
| 0,250 | 11,26 | 11,23 | 0,03 | 0,27%
| 0,500 | 10,93 | 10,92 | 0,01 | 0,09%
| 0,750 | 10,54 | 10,54 | 0 | 0,00%
| 1,000 | 1,62 | 1,69 | 0,07 | 4,32%
9,00 | 0,000 | 9,01 | 8,98 | 0,03 | 0,33%
| 0,100 | 8,34 | 8,32 | 0,02 | 0,24%
| 0,250 | 8,15 | 8,14 | 0,01 | 0,12%
| 0,500 | 7,85 | 7,85 | 0 | 0,00%
| 0,750 | 7,48 | 7,49 | 0,01 | 0,13%
| 1,000 | 0,99 | 0,98 | 0,01 | 1,01%
5,00 | 0,000 | 5,01 | 5,01 | 0 | 0,00%
| 0,100 | 4,22 | 4,25 | 0,03 | 0,71%
| 0,250 | 3,94 | 3,97 | 0,03 | 0,76%
| 0,500 | 3,53 | 3,58 | 0,05 | 1,42%
| 0,750 | 3,08 | 3,14 | 0,06 | 1,95%
| 1,000 | 0,94 | 1 | 0,06 | 6,38%

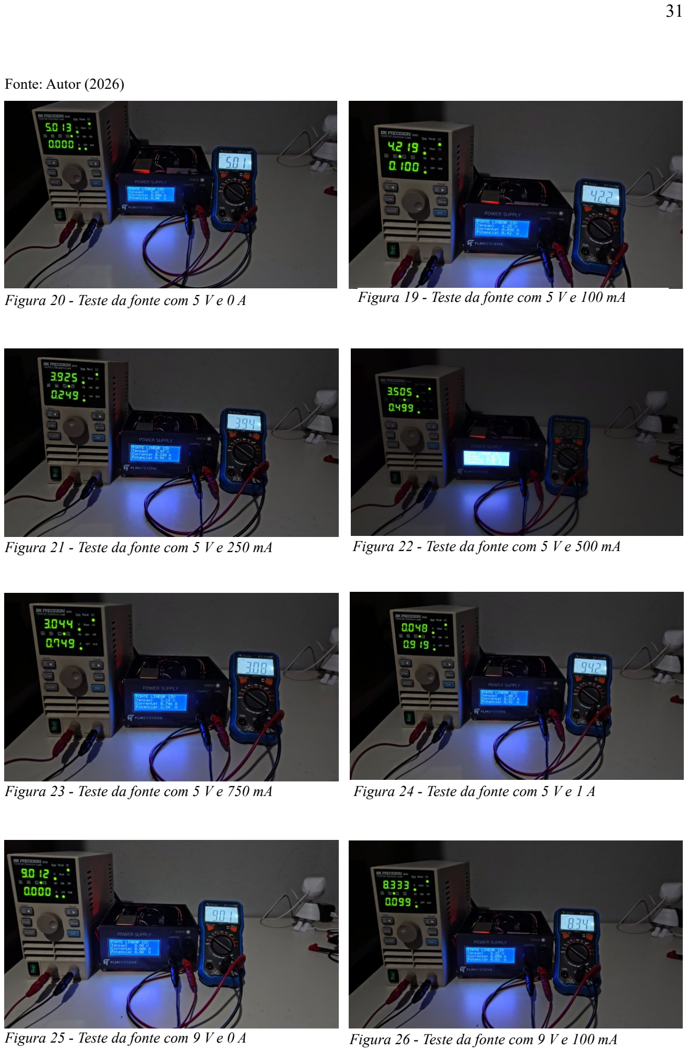
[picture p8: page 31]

Figura 20 - Teste da fonte com 5 V e 0 A | Figura 19 - Teste da fonte com 5 V e 100 mA
Figura 21 - Teste da fonte com 5 V e 250 mA | Figura 22 - Teste da fonte com 5 V e 500 mA
Figura 23 - Teste da fonte com 5 V e 750 mA | Figura 24 - Teste da fonte com 5 V e 1 A
Figura 25 - Teste da fonte com 9 V e 0 A | Figura 26 - Teste da fonte com 9 V e 100 mA

Fonte: Autor (2026)

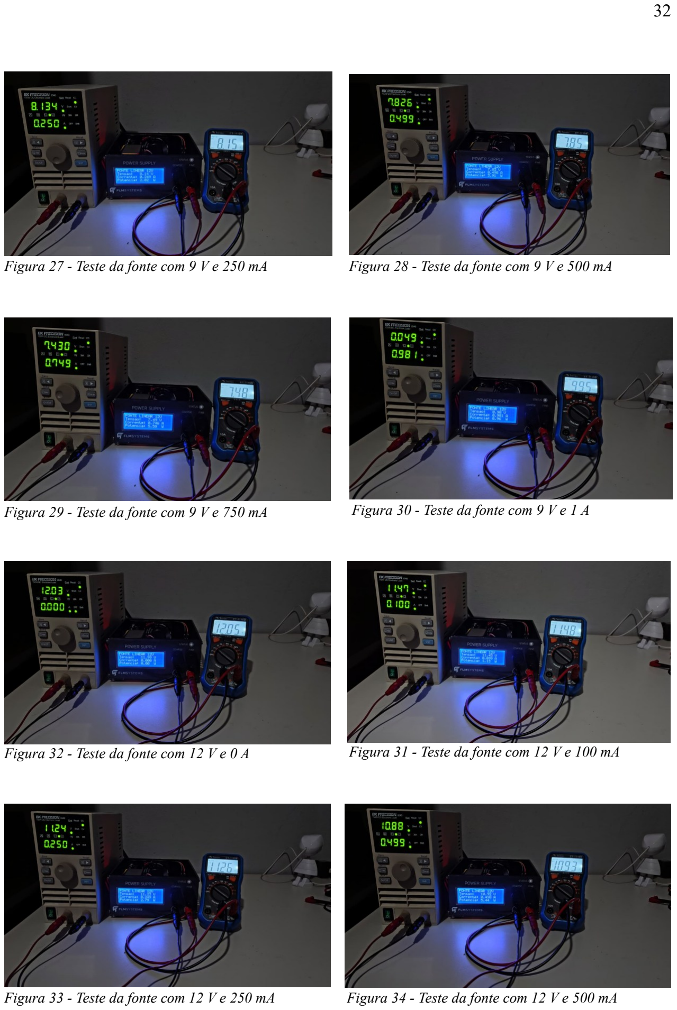
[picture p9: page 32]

Figura 27 - Teste da fonte com 9 V e 250 mA | Figura 28 - Teste da fonte com 9 V e 500 mA
Figura 29 - Teste da fonte com 9 V e 750 mA | Figura 30 - Teste da fonte com 9 V e 1 A
Figura 32 - Teste da fonte com 12 V e 0 A | Figura 31 - Teste da fonte com 12 V e 100 mA
Figura 33 - Teste da fonte com 12 V e 250 mA | Figura 34 - Teste da fonte com 12 V e 500 mA

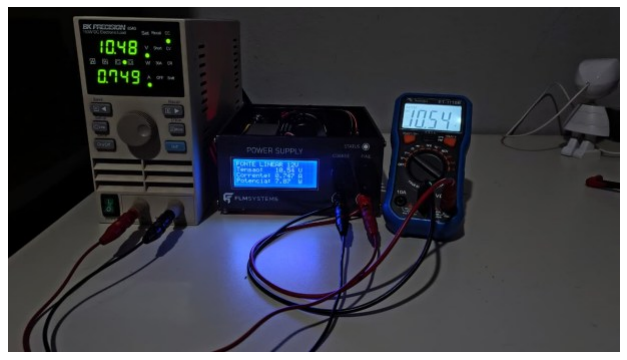
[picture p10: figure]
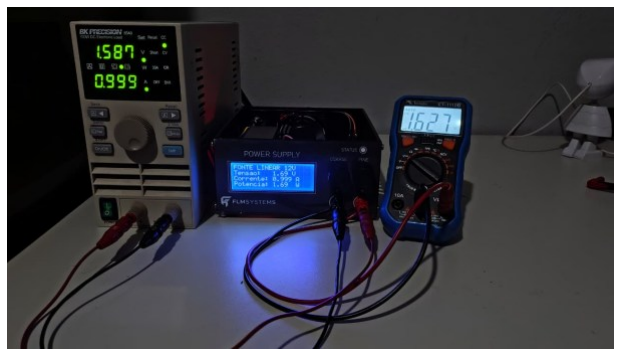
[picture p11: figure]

Figura 36 - Teste da fonte com 12 V e 750 mA | Figura 35 - Teste da fonte com 12 V e 1 A

### 4.2 Teste de Sobrecorrente

Para o teste de sobrecorrente, foi aplicada uma carga próxima à corrente limite do

projeto que foi calculado teoricamente na Equação 6, era esperado o desarmamento da fonte

quando próximo à corrente limite, que foi ocorrido com sucesso.

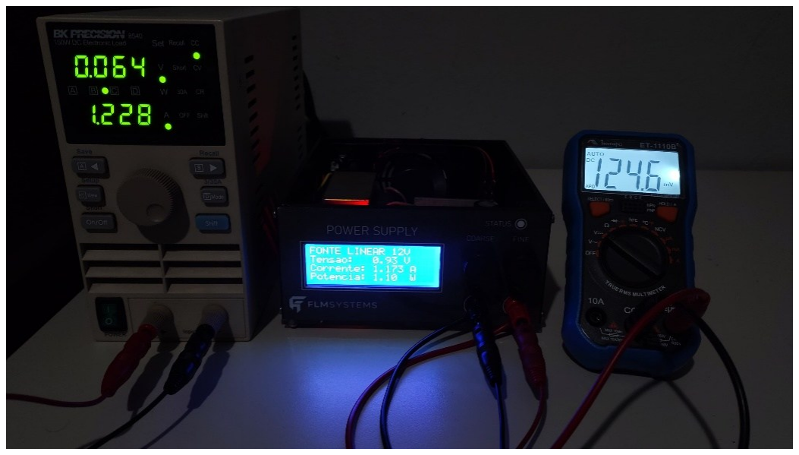
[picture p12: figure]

Figura 37 - Teste de sobrecorrente

Como visto na Figura 19, quando a carga atinge aproximadamente 1,23 A, a fonte

desarma e começa uma exponencial queda de tensão, isso garante a competência e

funcionalidade do sistema de proteção da fonte.

ERRO =

Valor teorico − Valor pratico Valor teorico

× 100% →

1,27 A − 1,23 A
1,27 A

× 100% = 3,1 %

Equação 20 - Erro do sistema de proteção da fonte

### 5 Discussão

A porcentagem de erro entre valores práticos e teóricos é justificada facilmente com o

aumento da carga nos testes da fonte, o normal é haver uma queda de tensão pois se trata de

uma fonte linear, que é motivada pela resistência interna dos componentes e a elevação da

temperatura da fonte conforme uma corrente elevada, porém a margem de erro é aceitável.

O sistema de proteção da fonte também obteve uma resposta positiva, o erro calculado

na Equação 20 é mínimo, e entende-se que se motiva pela tolerância nominal dos componentes

ou até mesmo, a alta temperatura conforme uma carga elevada.

A parte digital da fonte não apresentou erros, as oscilações e ruídos internos da fonte

foram filtrados através do microcontrolador. O algoritmo utilizado estabilizou a exibição dos

valores apresentados no display e foram precisos.

### 6 Conclusão

O projeto obteve todos os objetivos concluídos de forma clara e correta, desde a

construção do gabinete da fonte até os cálculos teóricos para a criação de um rascunho da PCB

foram totalmente importantes e úteis para o entendimento sobre o tema e os conceitos

abordados.

Todas as etapas do projeto foram realizadas corretamente e no prazo certo previsto,

mesmo que com pouco tempo, o projeto foi construído e comprovou sua funcionalidade. A

principal função da fonte, que era ajustar uma tensão de até 12 V funcionou perfeitamente,

porém, não só essa função operou corretamente, o sistema de proteção da fonte foi testado e

respondeu positivamente, o display controlado pelo ESP32 através do código de programação

também teve uma boa resposta, assim como todo o projeto.

O projeto é funcional, porém, algumas melhorias fariam esse projeto melhor, como

substituir a regulação linear por um circuito de chaveamento aumentando a eficiência e

funcionalidade da fonte, adicionar um limitador de corrente ajustável ao invés de uma corrente

máxima fixa, entre outras ideias que com mais tempo, poderiam ser algumas melhorias.

Estudar os conceitos por trás deste projeto é importante e interessante, criar uma fonte

de bancada do zero é algo desafiador, porém, o processo de estudos e criação são totalmente

ligados ao curso, gerando mais entendimento para os criadores do projeto e propondo desafios

práticos com os estudos teóricos que são vistos no curso.

### 7 Referências

ASSOCIAÇÃO BRASILEIRA DE NORMAS TÉCNICAS. ABNT. NBR 14724: Trabalhos acadêmicos. Apresentação. Rio de Janeiro: ABNT, 2011.

ASSOCIAÇÃO BRASILEIRA DE NORMAS TÉCNICAS. ABNT. NBR 6023: Informação e documentação. Referências, elaboração. Rio de Janeiro: ABNT, 2018.

BOYLESTAD, Robert L. e NASHELSKY, L.- Dispositivos Eletrônicos e Teoria dos Circuitos. 8ed. Prentice Hall do Brasil, 1984/2011).

SADIKU, Matthew N. O.; MUSA, Sarhan M.; ALEXANDER, Charles K. Análise de

circuitos elétricos com aplicações. Bookman, 2013/2014.

PLACA ESP32: o que é, modelos, pinagem e como programar. VictorVision, 2022.

Disponível em: https://victorvision.com.br/blog/placa-esp32/. Acesso em: 2026.

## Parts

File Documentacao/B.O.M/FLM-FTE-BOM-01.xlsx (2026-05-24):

PROJETO: Fonte Linear Regulada 12V Equipe: FLM System
Referencia | Valor | Quantidade | Footprint
CN1,CN2 | AKZ700-2-5,08V | 2 | PCB-CONECTOR:AKZ300-2-5.08
Q1 | TIP120 | 1 | Package_TO_SOT_THT:TO-220-3_Vertical
R2 | 0,33R/5W | 1 | Resistor_THT:R_Axial_DIN0516_L15.5mm_D5.0mm_P5.08mm_Vertical
R4,R6,R7 | 0,22R/5W | 3 | Resistor_THT:R_Axial_DIN0516_L15.5mm_D5.0mm_P5.08mm_Vertical
RF1,RF2 | 15K | 2 | Resistor_THT:R_Axial_DIN0207_L6.3mm_D2.5mm_P2.54mm_Vertical
RG1 | 10K | 1 | Resistor_THT:R_Axial_DIN0207_L6.3mm_D2.5mm_P2.54mm_Vertical
RV1 | 11K | 1 | PCB-DISCRETO:POTENCIOMETRO
U2 | LM358N | 1 | PCB-CI:DIP8
R3 | 14K 1/4W | 1 | Resistor_THT:R_Axial_DIN0207_L6.3mm_D2.5mm_P7.62mm_Horizontal
R12 | 1K 1/4W | 1 | Resistor_THT:R_Axial_DIN0207_L6.3mm_D2.5mm_P7.62mm_Horizontal
Q2,Q3,Q4 | BC547 | 3 | PCB-DISCRETO:TRANSP(CBE)_BC547
REG1 | LM7812 | 1 | PCB-CI:LM78XX
J1 | BPSC-4 | 1 | Connector_PinHeader_2.54mm:PinHeader_1x04_P2.54mm_Vertical
J3 | BPSC-2 | 1 | Connector_PinSocket_2.54mm:PinSocket_1x02_P2.54mm_Vertical
C2,C4,C9,C10,C11,C13 | 0,1uF/50V | 6 | Capacitor_THT:C_Disc_D5.0mm_W2.5mm_P5.00mm
D5 | 1N4744A | 1 | Diode_THT:D_DO-41_SOD81_P10.16mm_Horizontal
ST1 | KFC-A06 4,3 | 1 | PCB-GERAL:PUSHBOTON
LD1 | LED Bicolor R/G 5mm | 1 | PCB-DISCRETO:LED5MM_BICOLOR_K
J2 | MCS-6 | 1 | Connector_PinSocket_2.54mm:PinSocket_1x06_P2.54mm_Vertical
D1,D2,D3,D4 | 1N5406 | 4 | Diode_THT:D_DO-201AD_P15.24mm_Horizontal
REG3 | LD1117DT33TR | 1 | PCB-CI:DPAK_LD1117
REG2 | LM2576D2TR4-5G | 1 | PCB-CI:D2PAK-5
D6 | SS36 | 1 | PCB-DISCRETO:DO-214AA_SMB_J-BEND
L1 | 100uH | 1 | PCB-GERAL:74477120
U1 | ESP32-WROOM-32E-N8 | 1 | PCB-GERAL:ESP32-WROOM-32E-N8
C3,C8 | 100uF/25V | 2 | PCB-DISCRETO:CAP100UF25V
C7 | 100uF/50V | 1 | PCB-DISCRETO:CAP100UF25V
C12 | 10uF/16V | 1 | PCB-DISCRETO:CAP100UF25V
C6 | 1000uF/25V | 1 | PCB-DISCRETO:CAP_1000UF_50V
C1,C5 | 4700uF/35V | 2 | Capacitor_THT:CP_Radial_D18.0mm_P7.50mm
R11 | 150R | 1 | Resistor_THT:R_Axial_DIN0207_L6.3mm_D2.5mm_P7.62mm_Horizontal
R10 | 180R | 1 | Resistor_THT:R_Axial_DIN0207_L6.3mm_D2.5mm_P7.62mm_Horizontal
R1 | 330R 1/4W | 1 | Resistor_THT:R_Axial_DIN0207_L6.3mm_D2.5mm_P7.62mm_Horizontal
R8,R9,R13 | 10K 1/4W | 3 | Resistor_THT:R_Axial_DIN0207_L6.3mm_D2.5mm_P7.62mm_Horizontal

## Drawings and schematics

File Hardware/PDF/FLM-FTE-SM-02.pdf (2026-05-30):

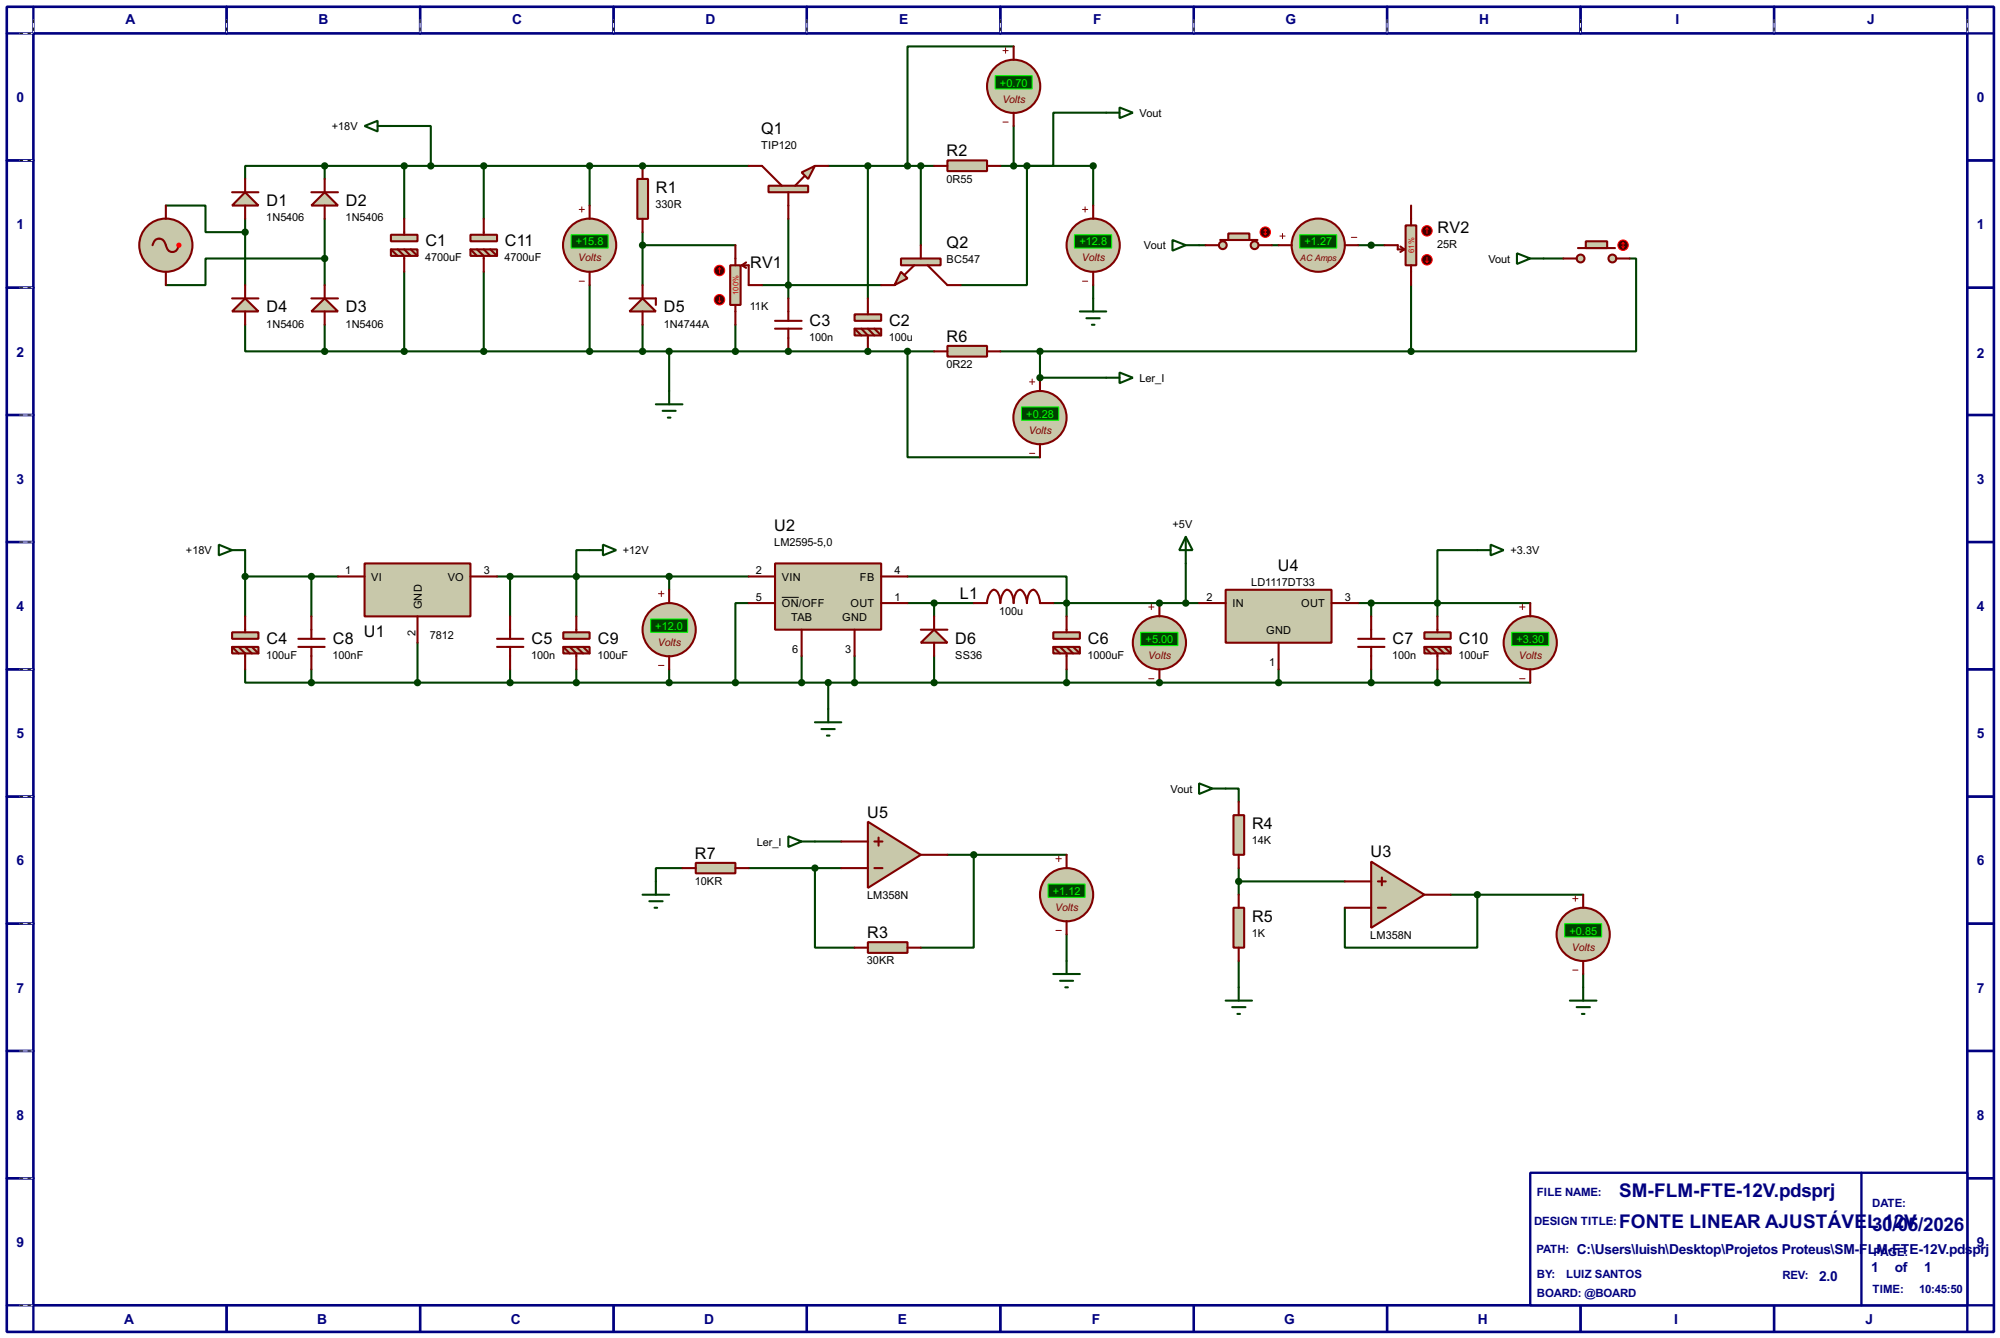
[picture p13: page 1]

SM-FLM-FTE-12V.pdsprj

FILE NAME:
DESIGN TITLE:FONTE LINEAR AJUSTÁVEL 12V

PATH: C:\Users\luish\Desktop\Projetos Proteus\SM-FLM-FTE-12V.pdsprj

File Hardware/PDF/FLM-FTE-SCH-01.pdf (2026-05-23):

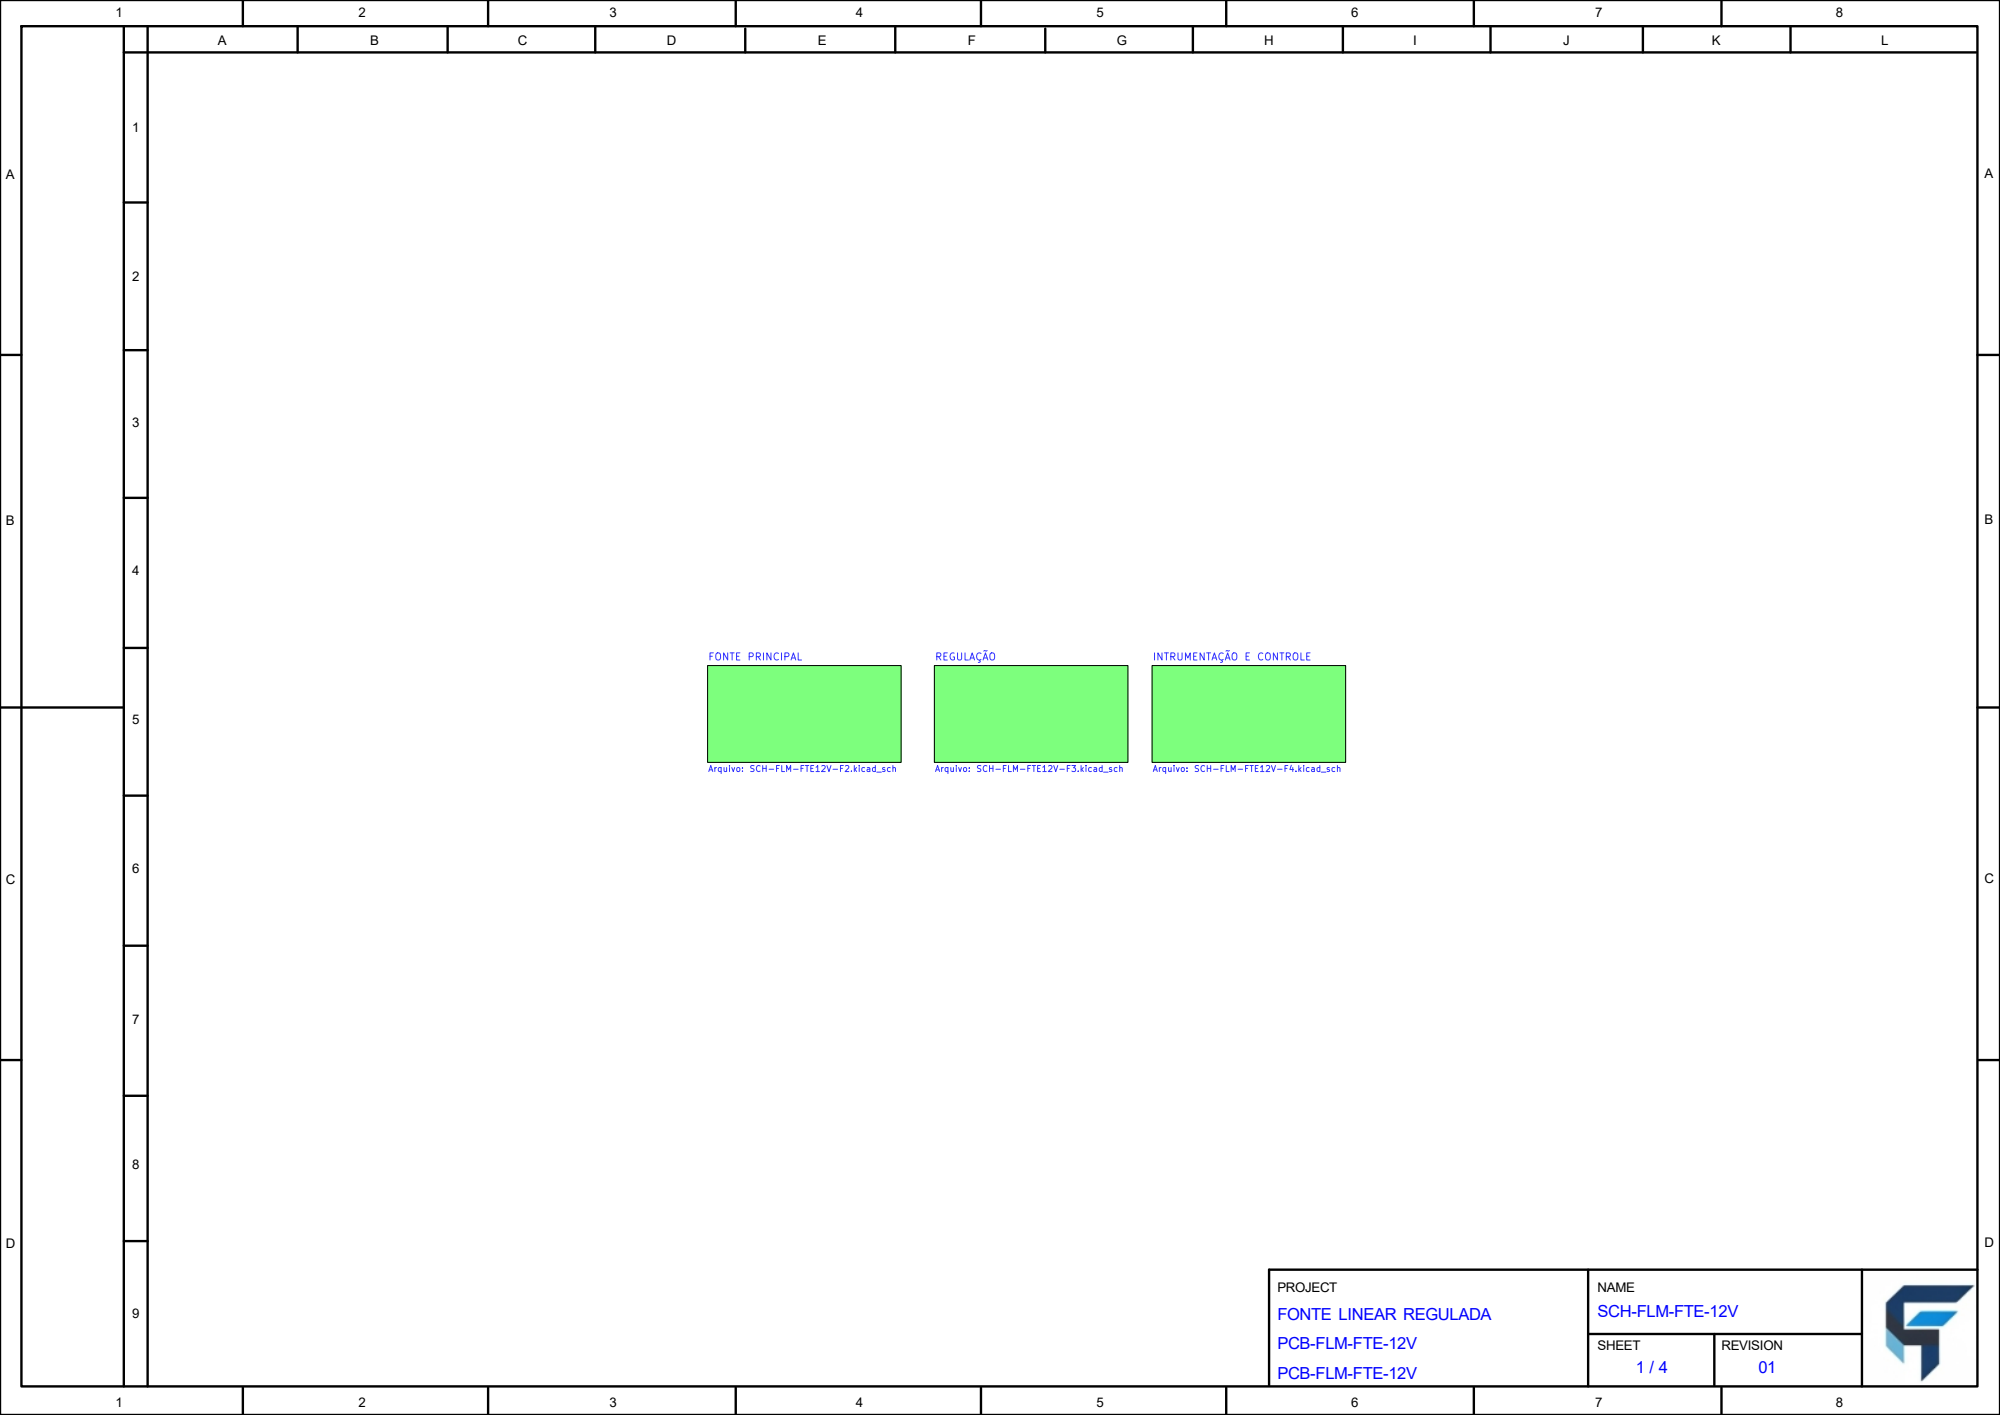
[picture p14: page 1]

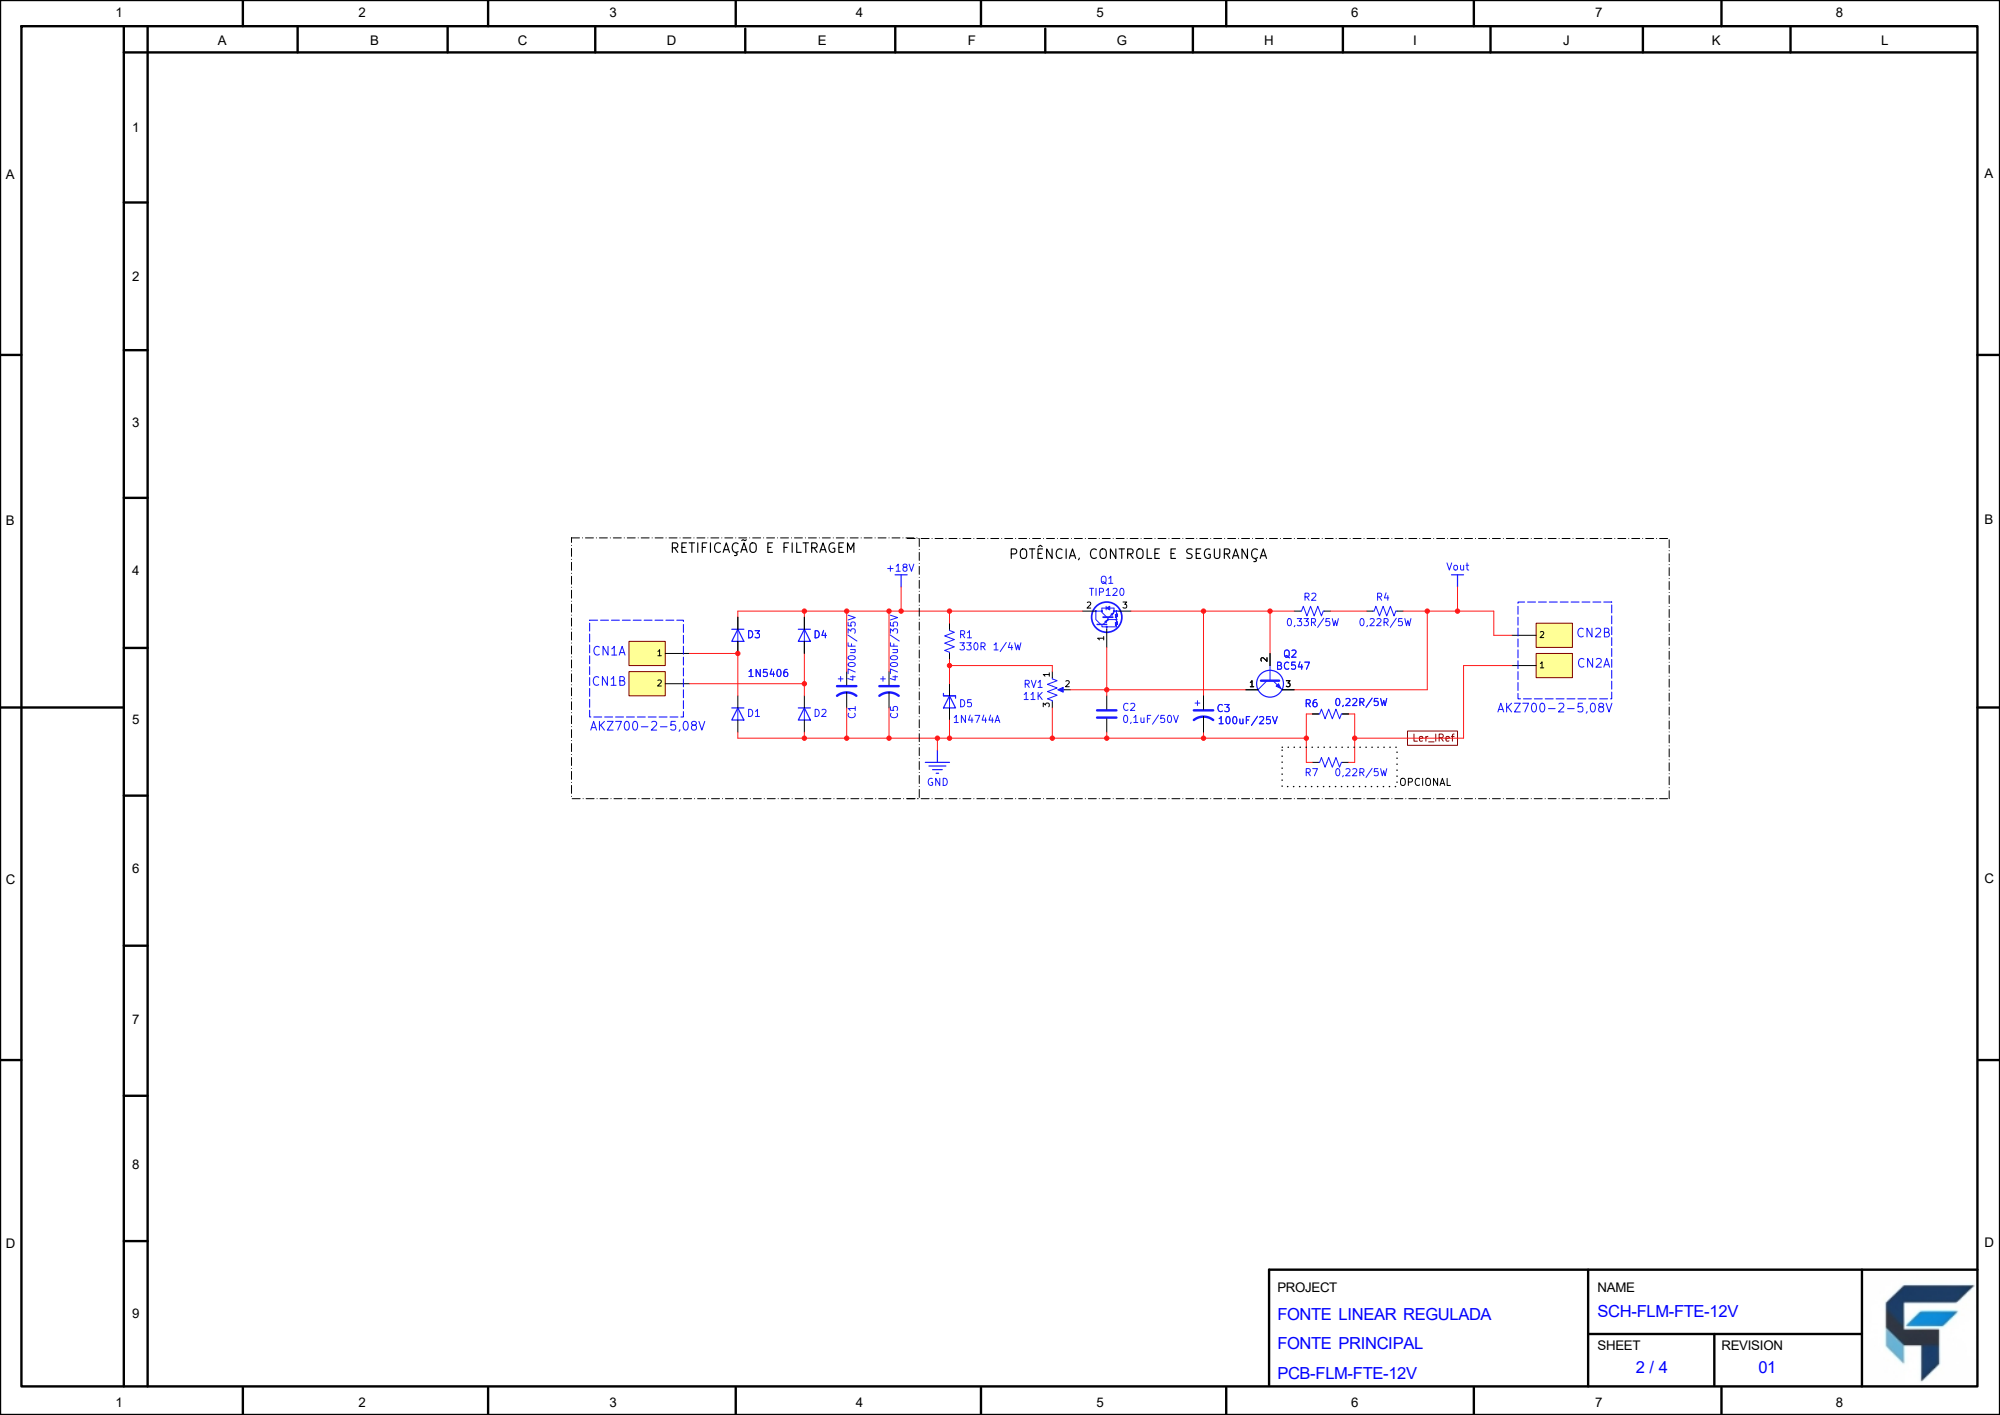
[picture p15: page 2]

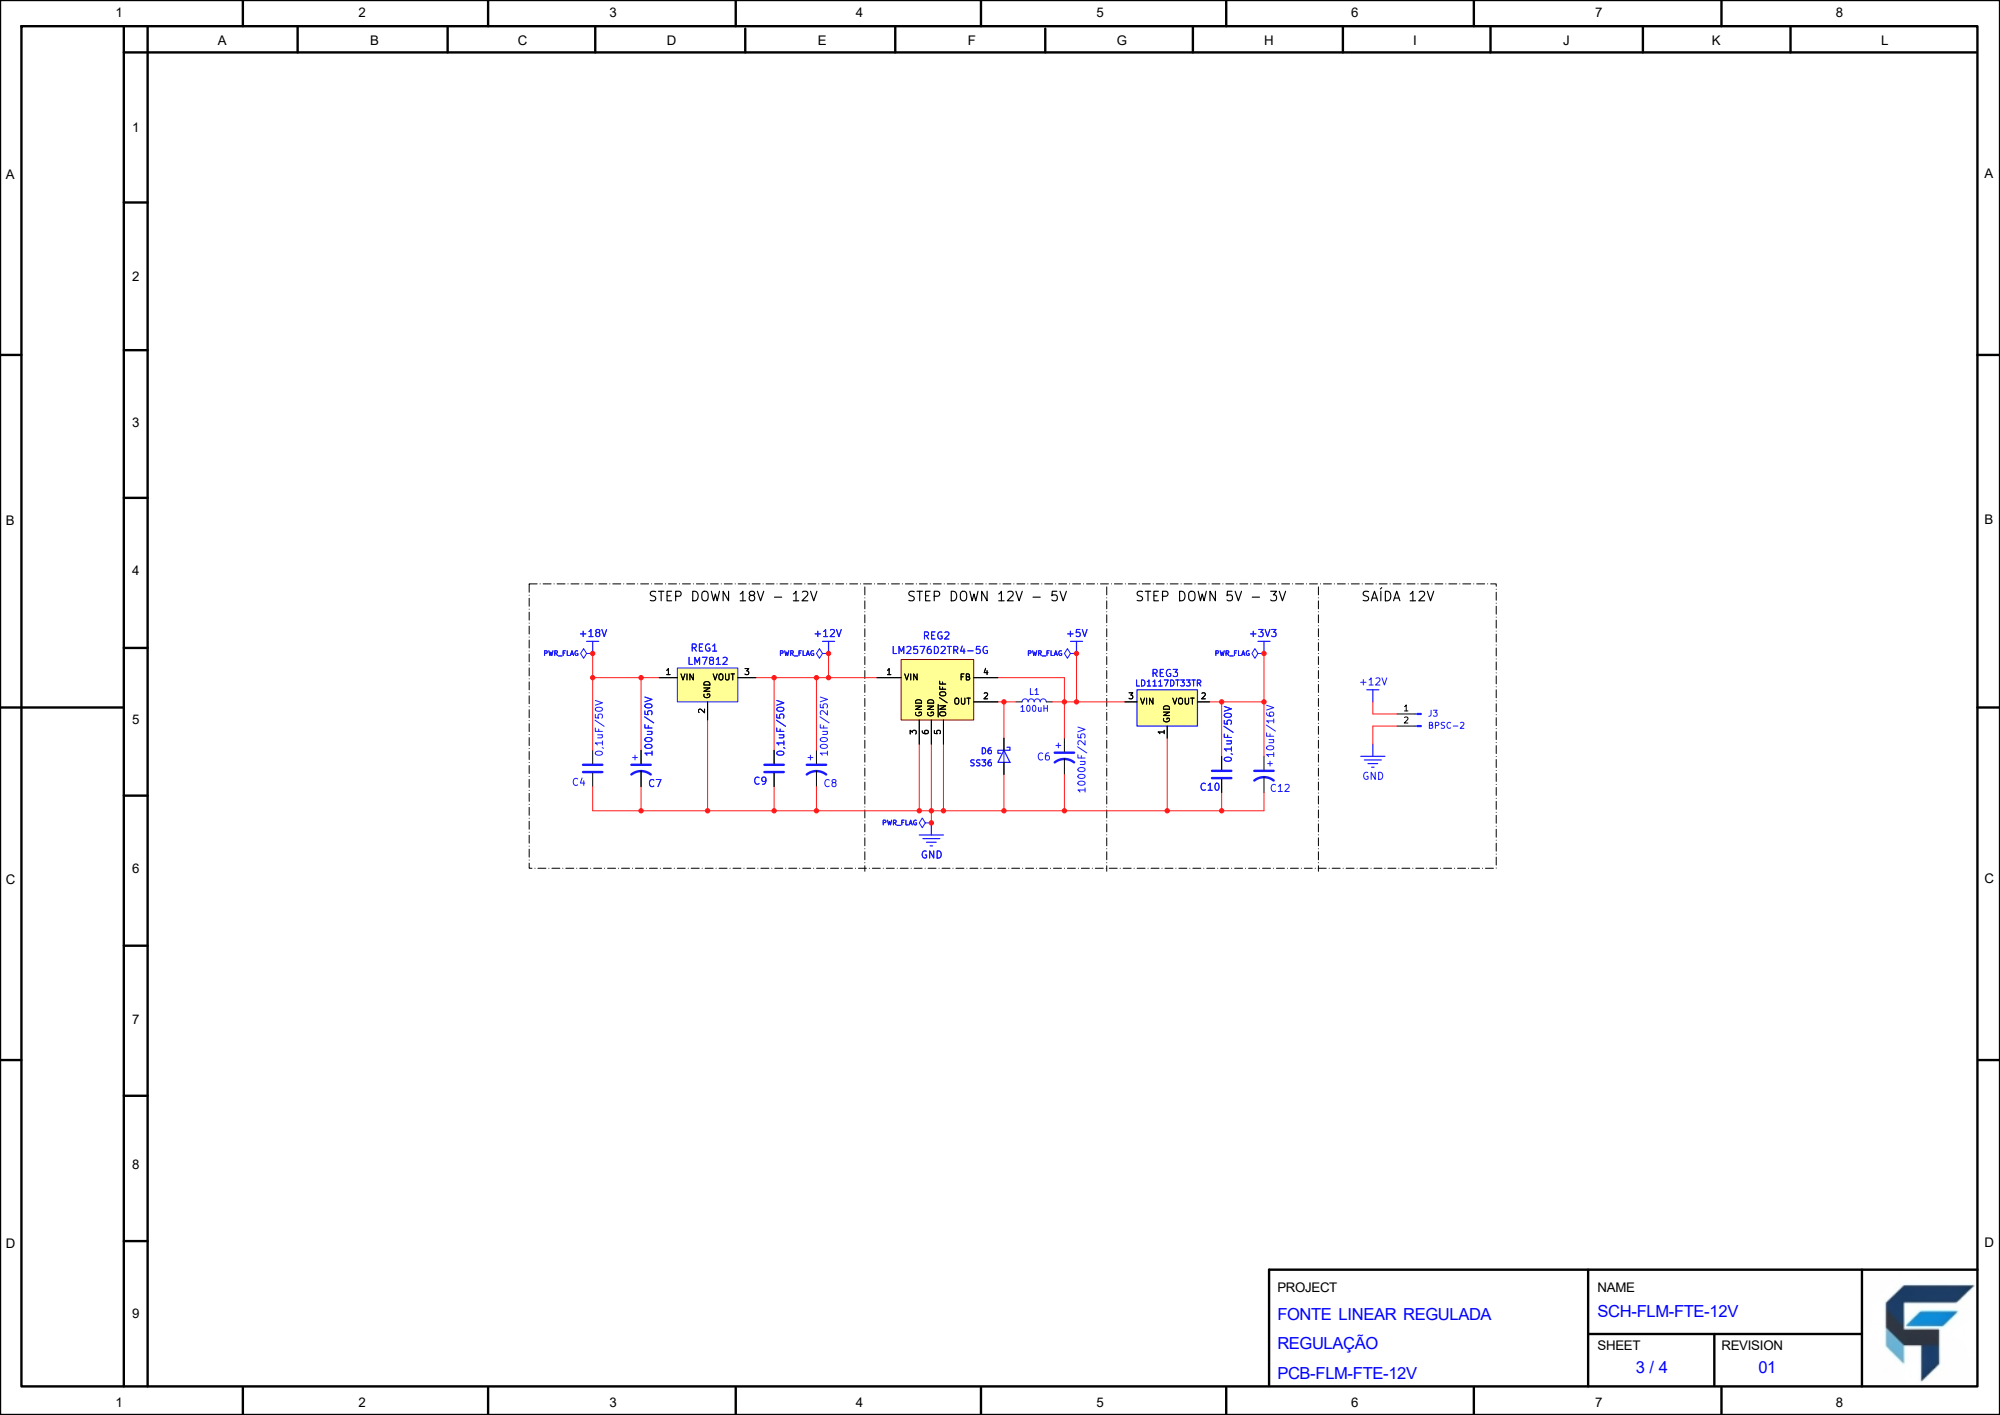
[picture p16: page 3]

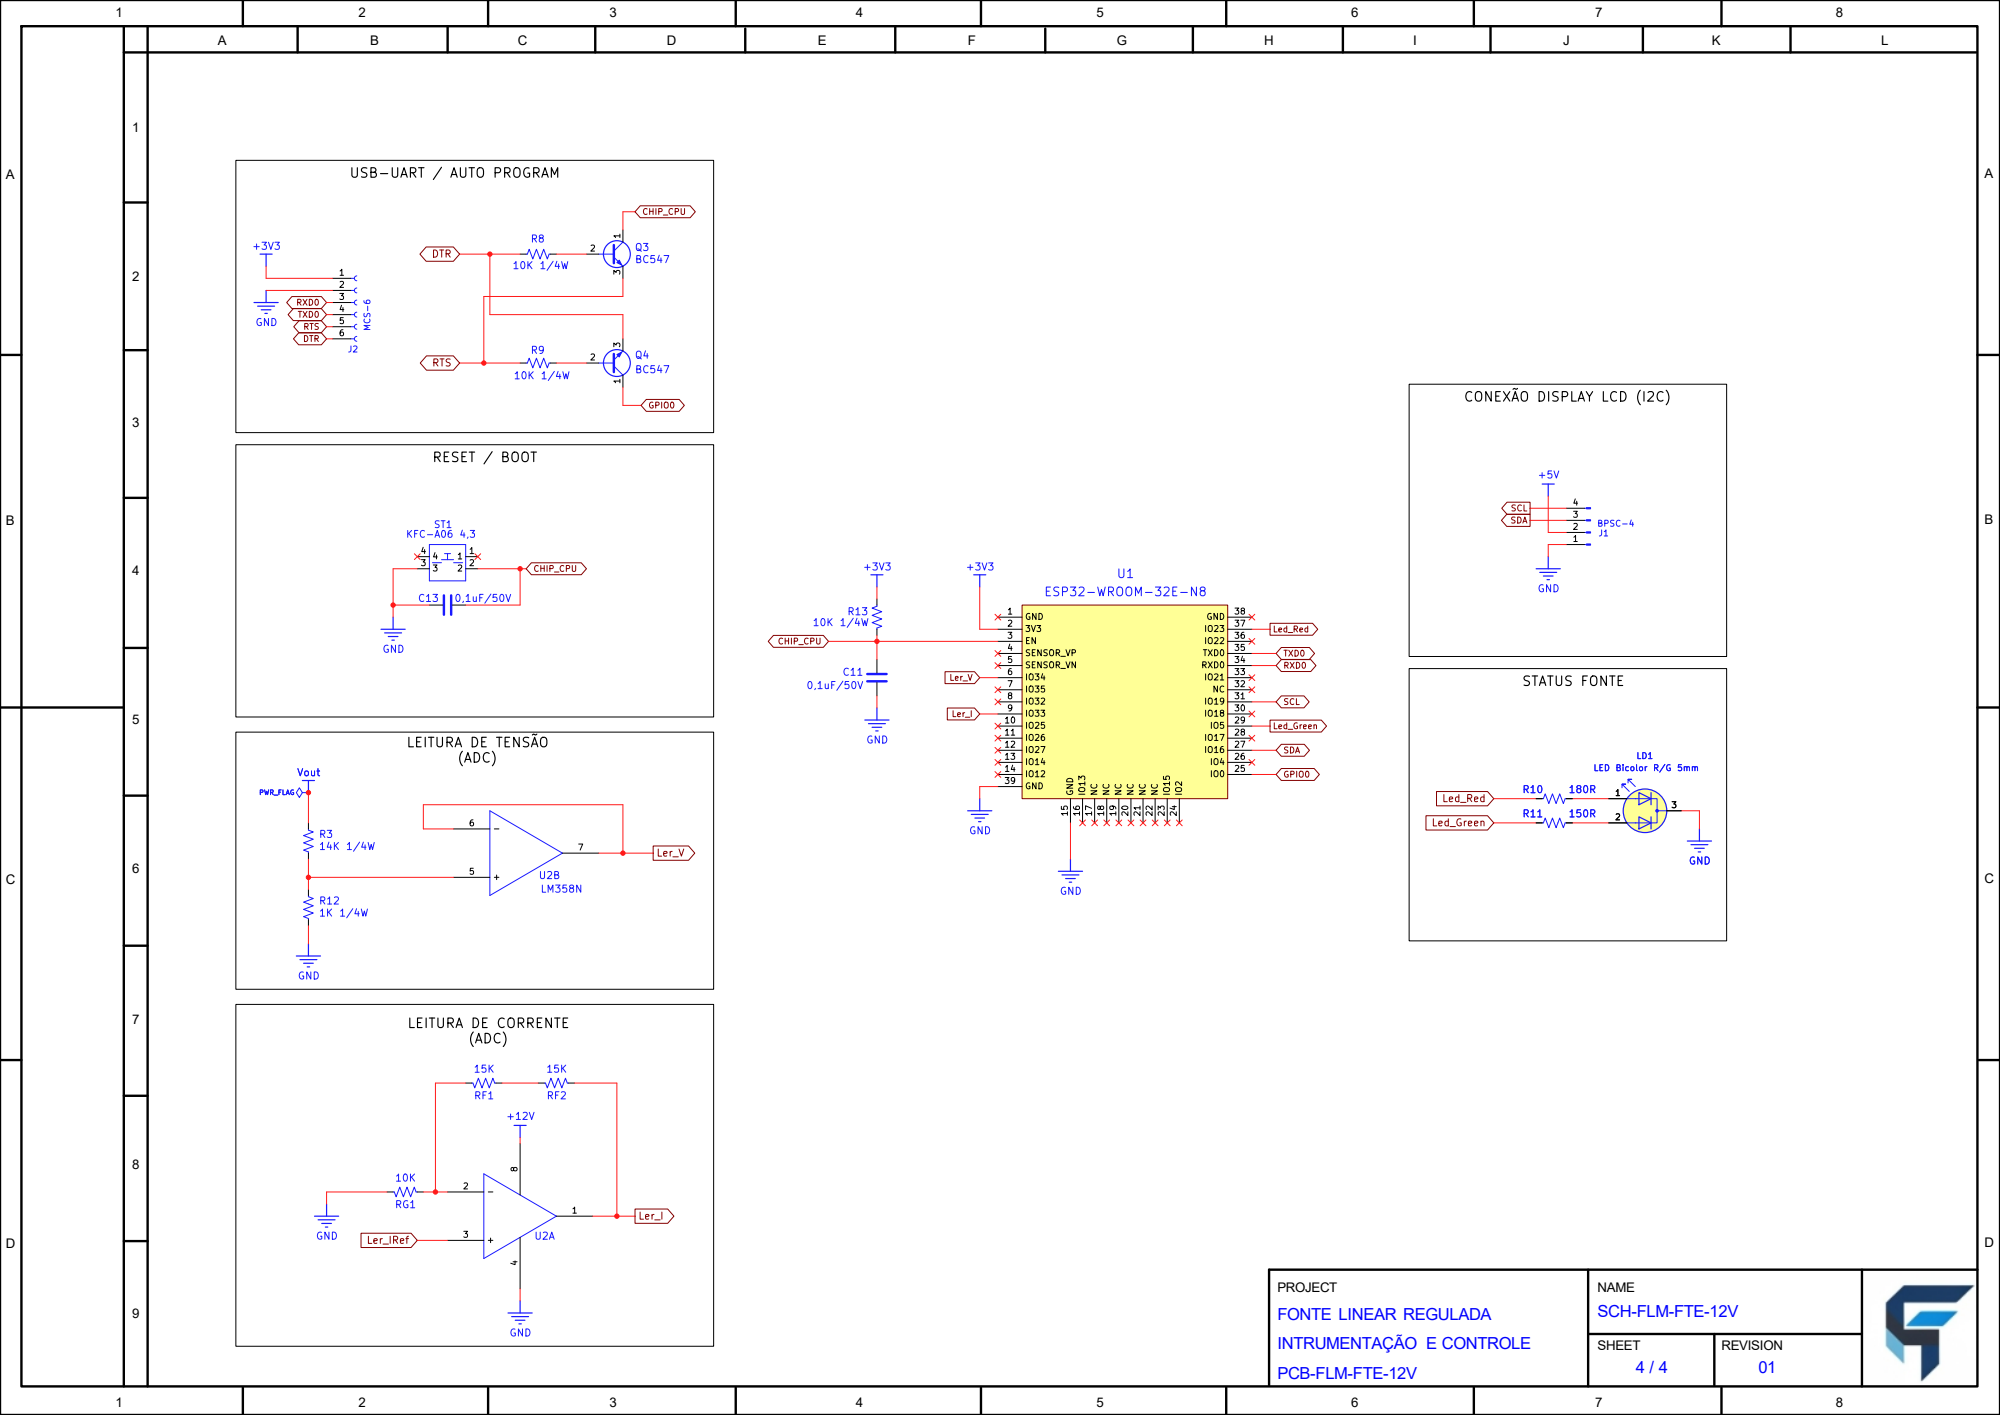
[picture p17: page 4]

USB-UART / AUTO PROGRAM

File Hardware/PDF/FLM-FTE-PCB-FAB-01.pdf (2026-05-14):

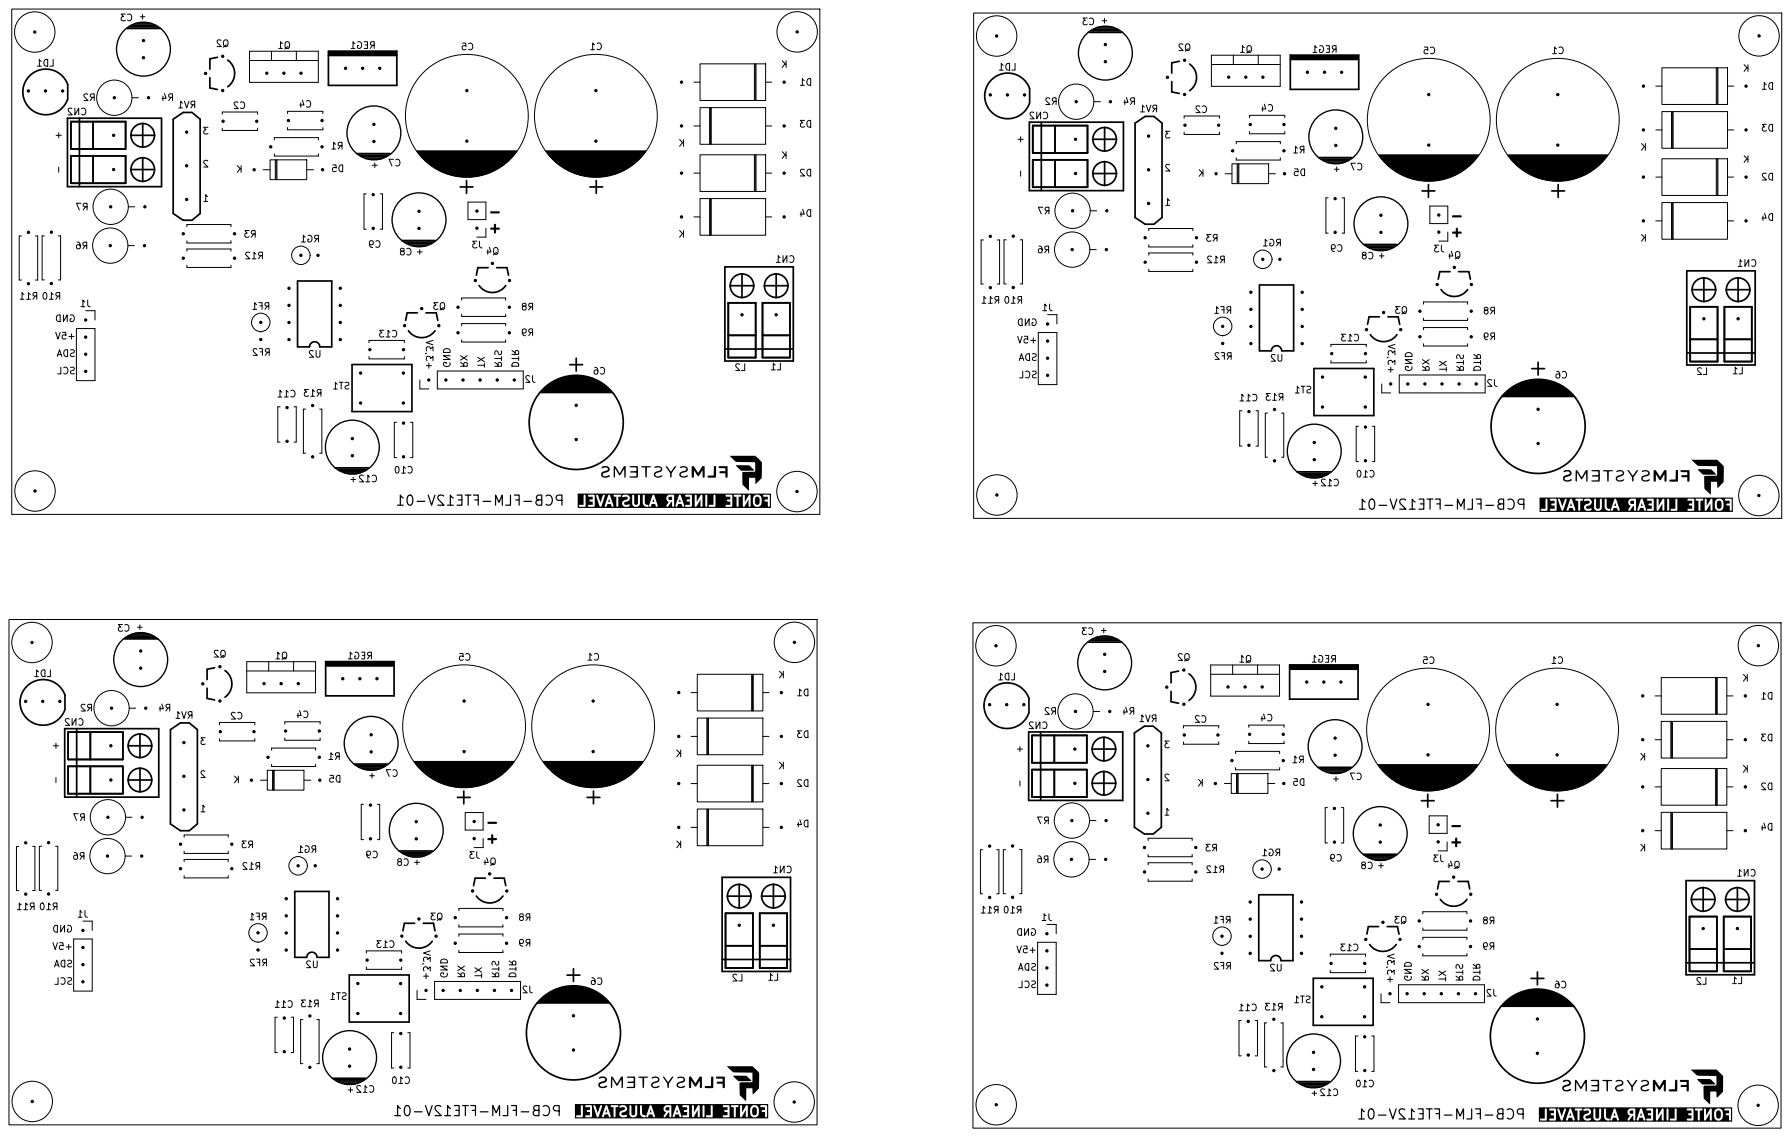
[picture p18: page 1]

1 +3,3V GND TXDTR +5V SCL GND

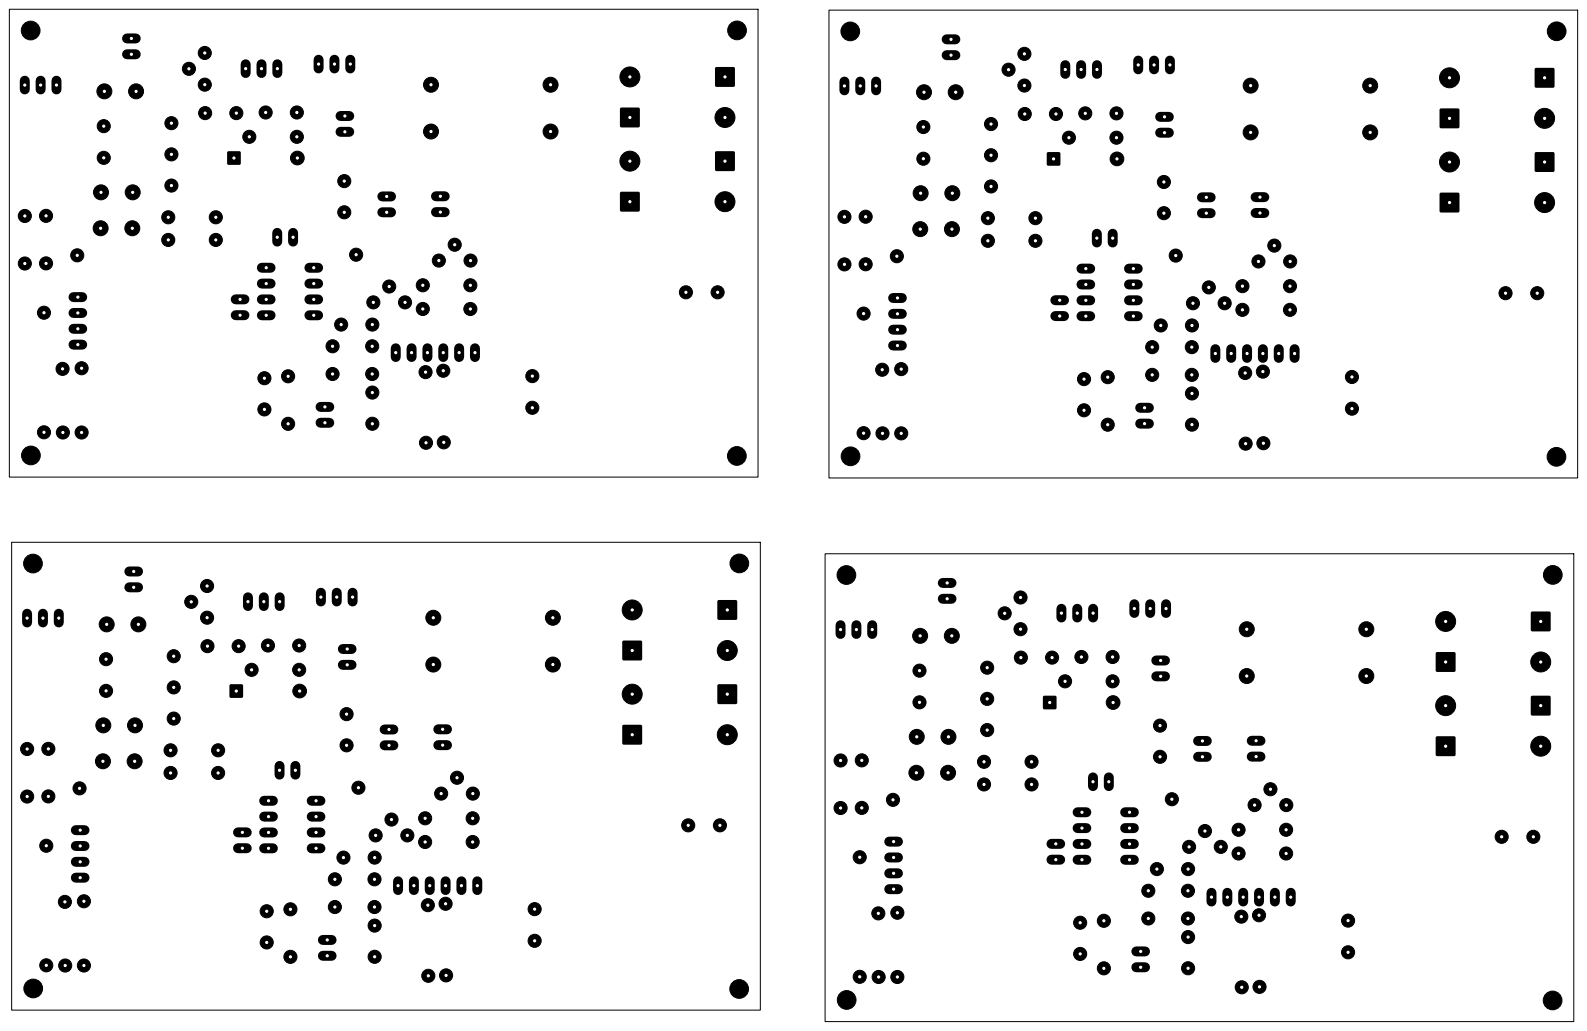
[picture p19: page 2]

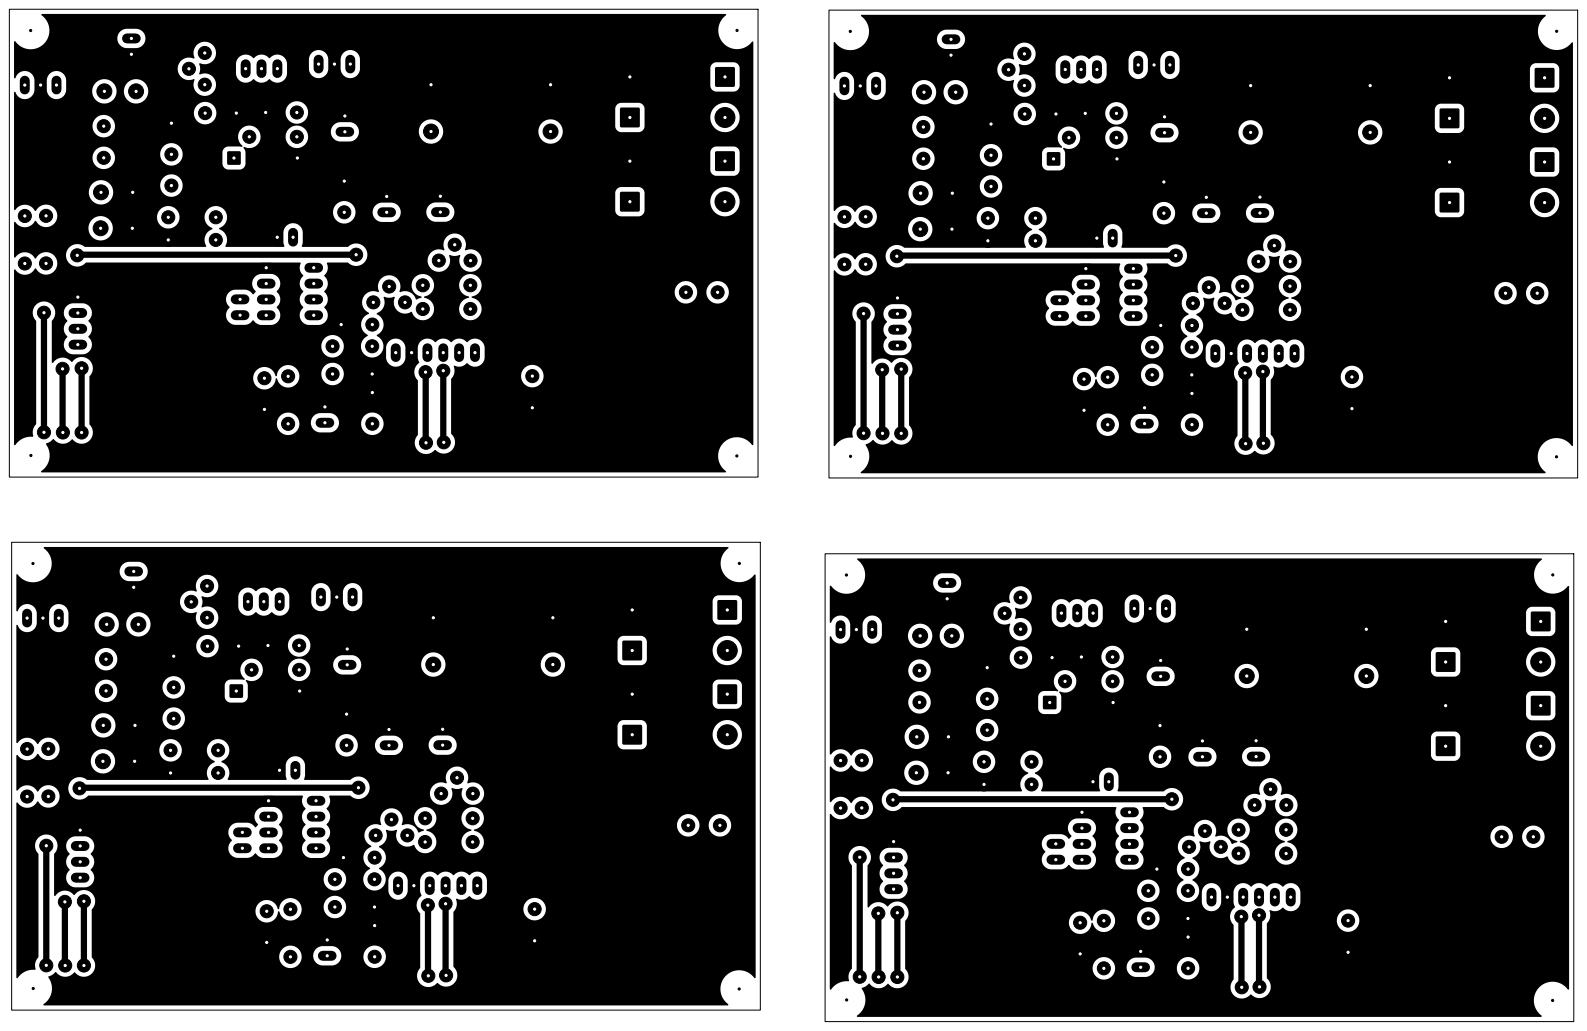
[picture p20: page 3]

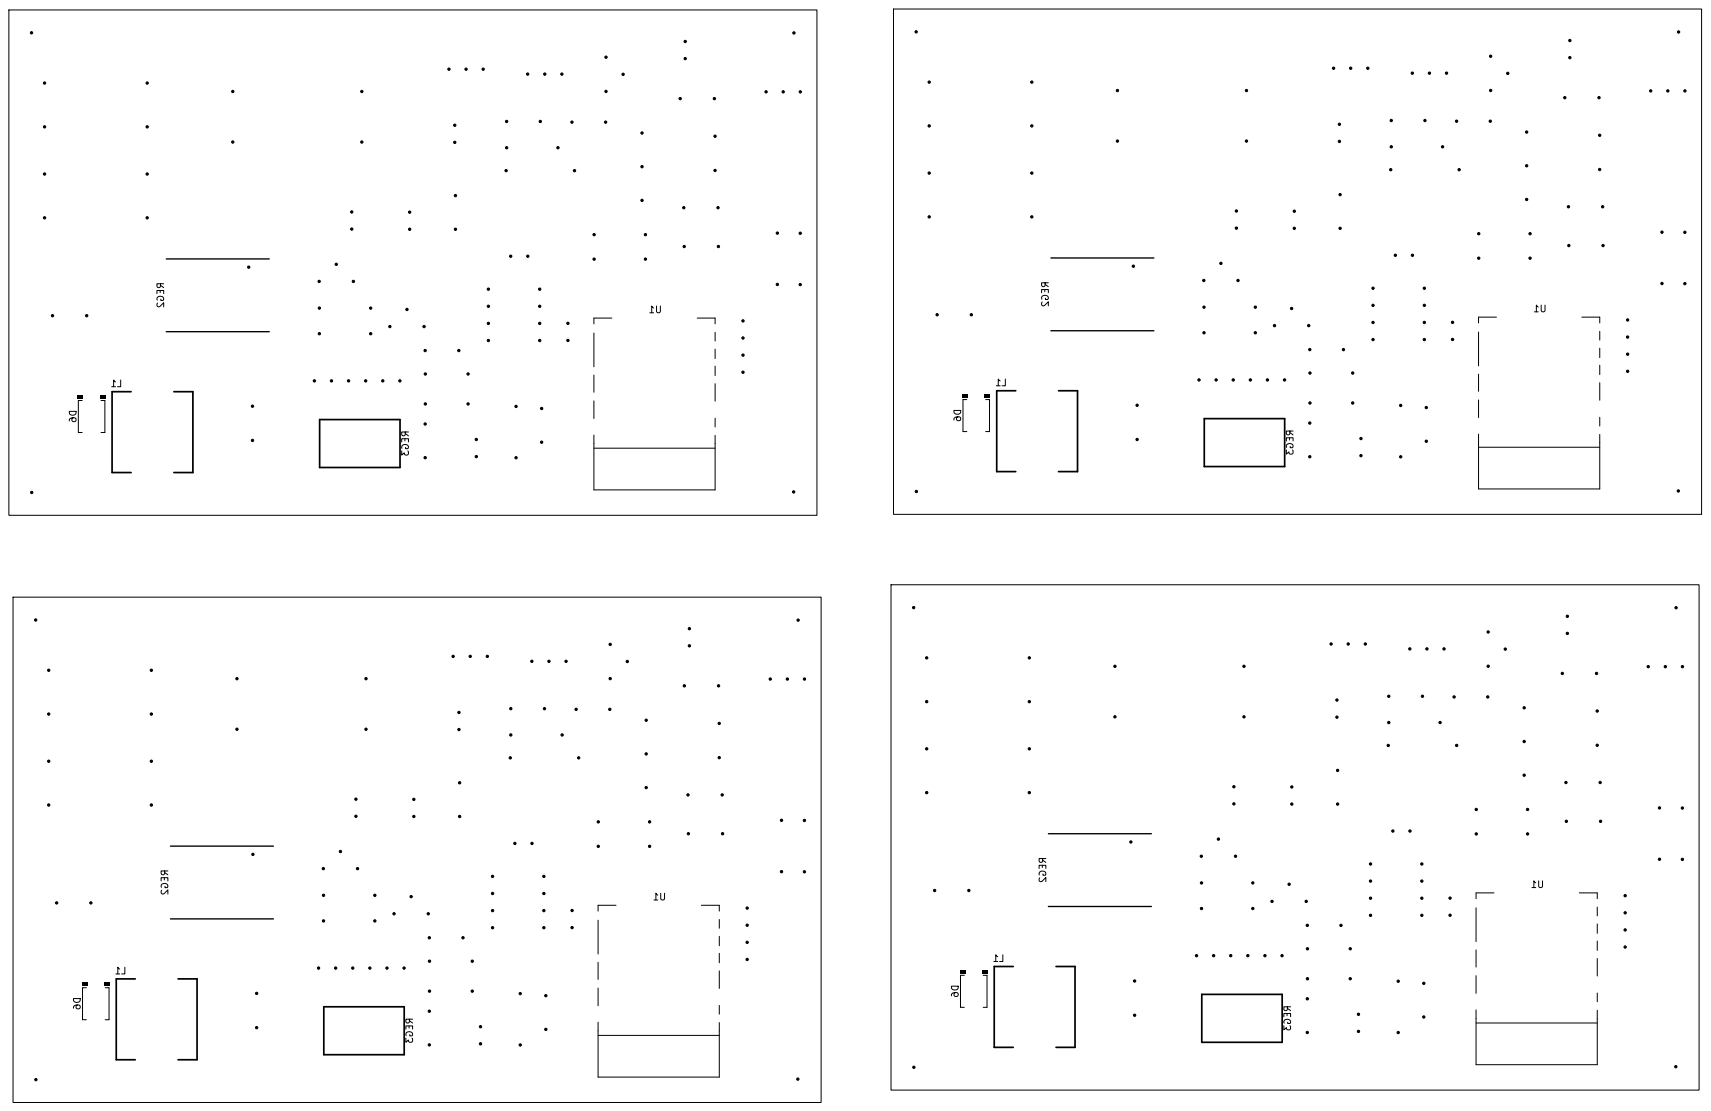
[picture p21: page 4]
U1 REG2 D6 REG3; L1 U1 REG2 D6 REG3; U1 REG2 D6 REG3 L1 U1 D6 REG3 REG2

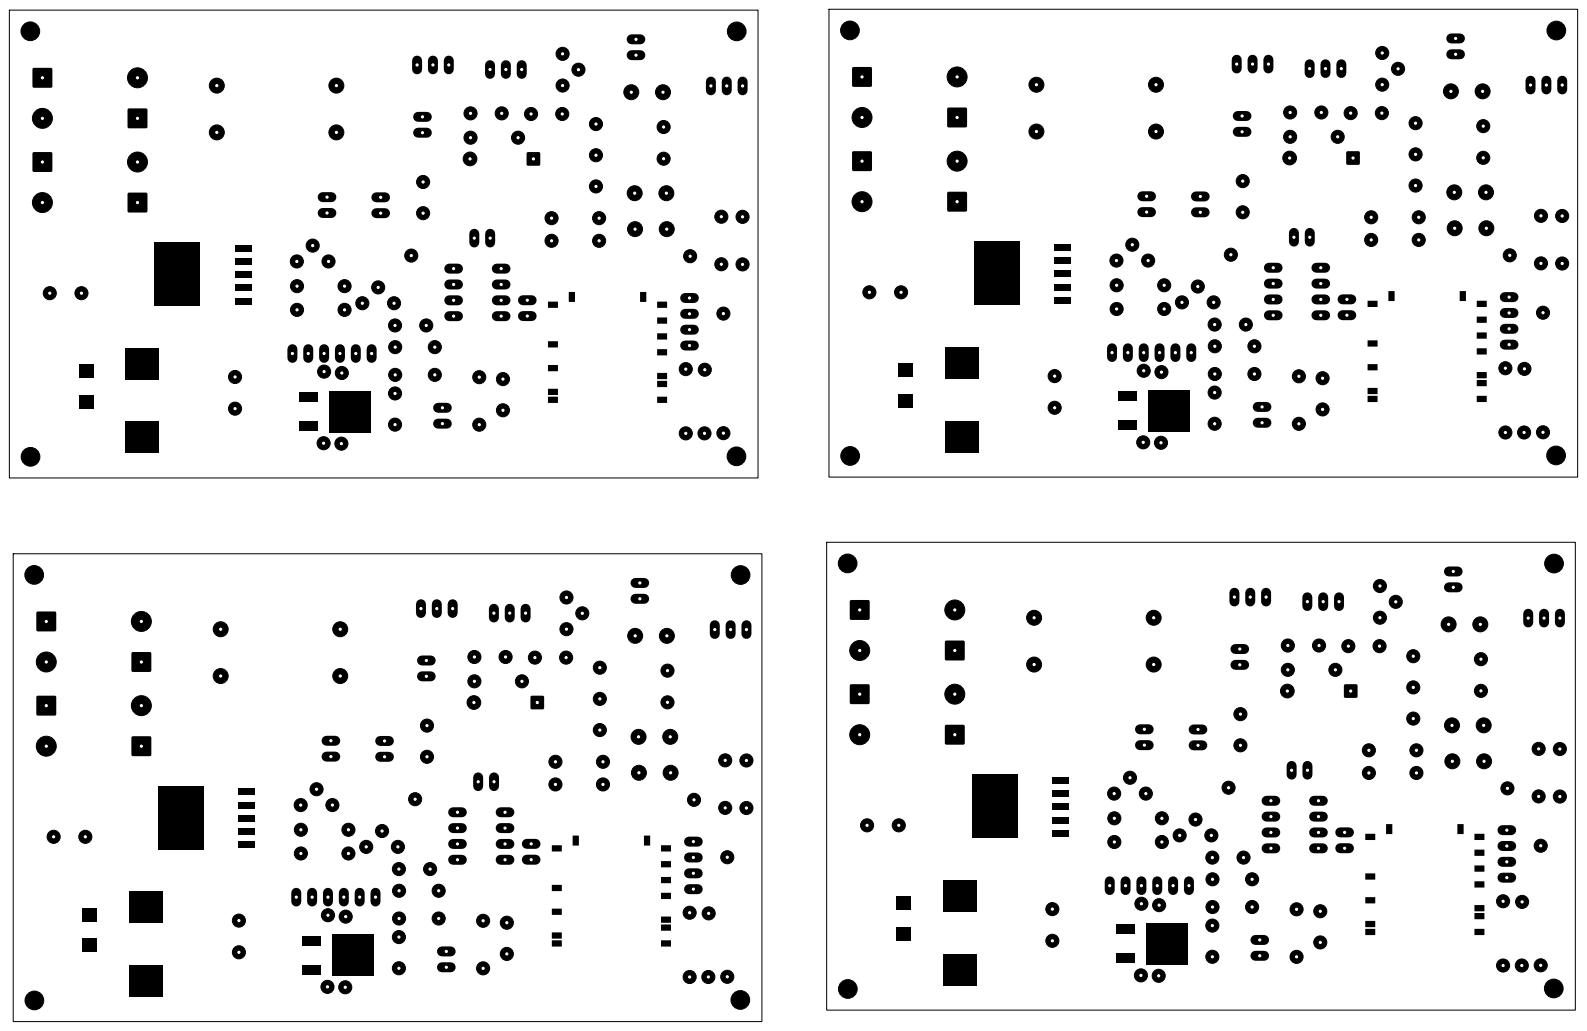
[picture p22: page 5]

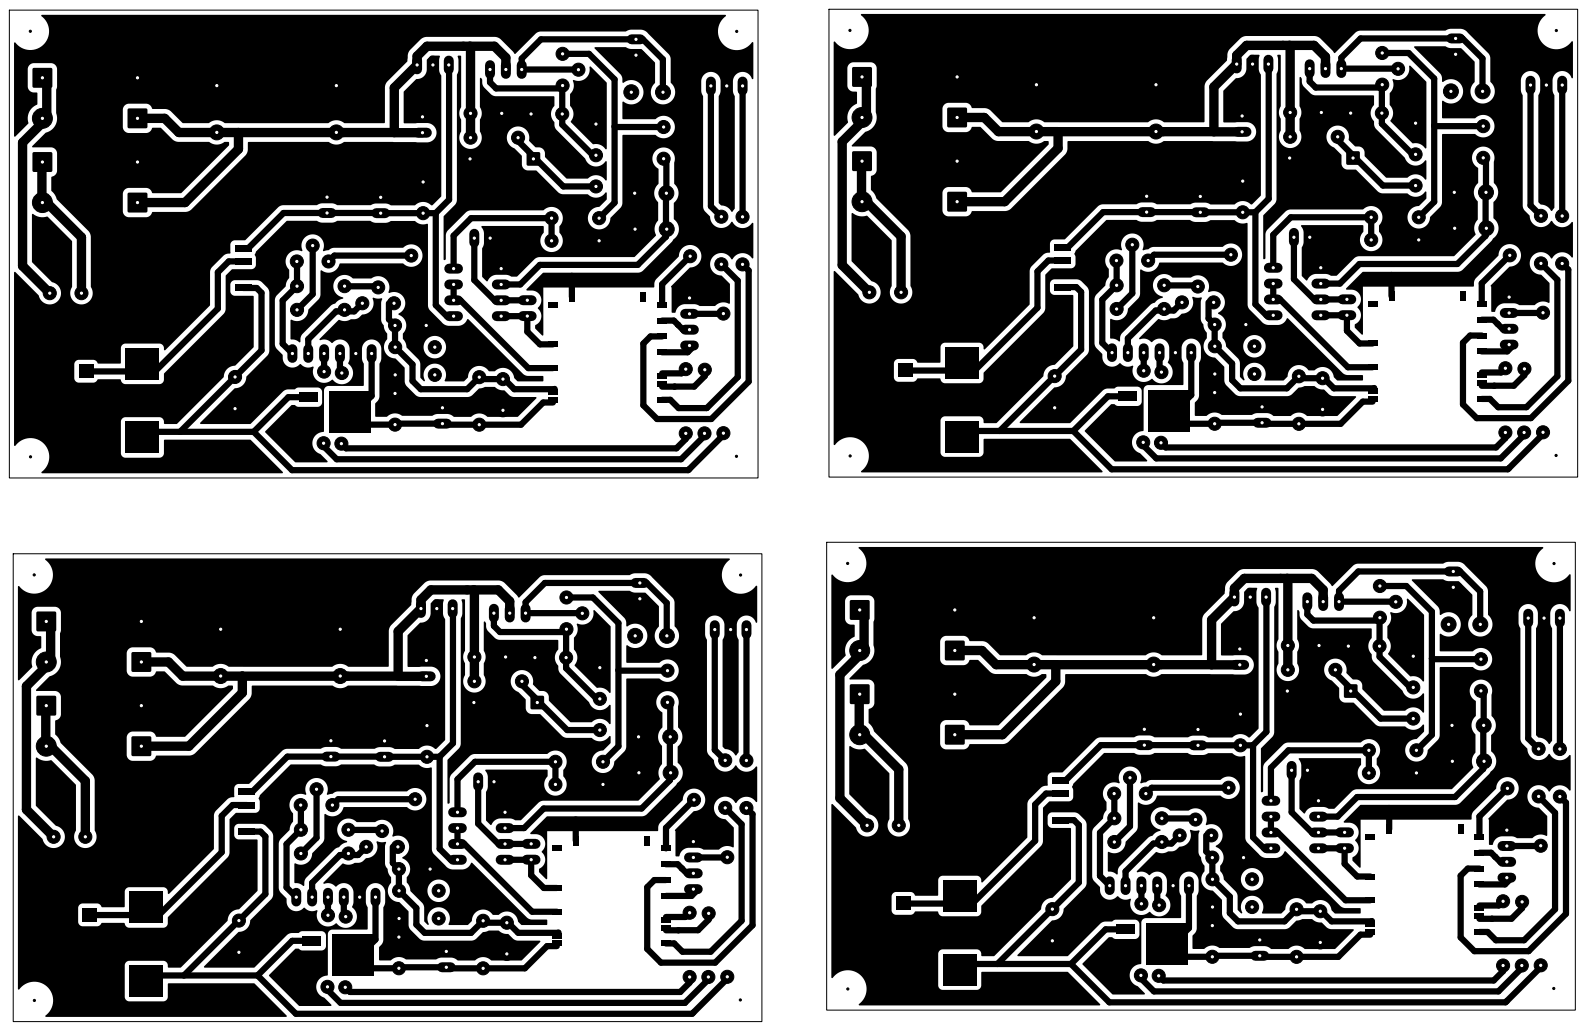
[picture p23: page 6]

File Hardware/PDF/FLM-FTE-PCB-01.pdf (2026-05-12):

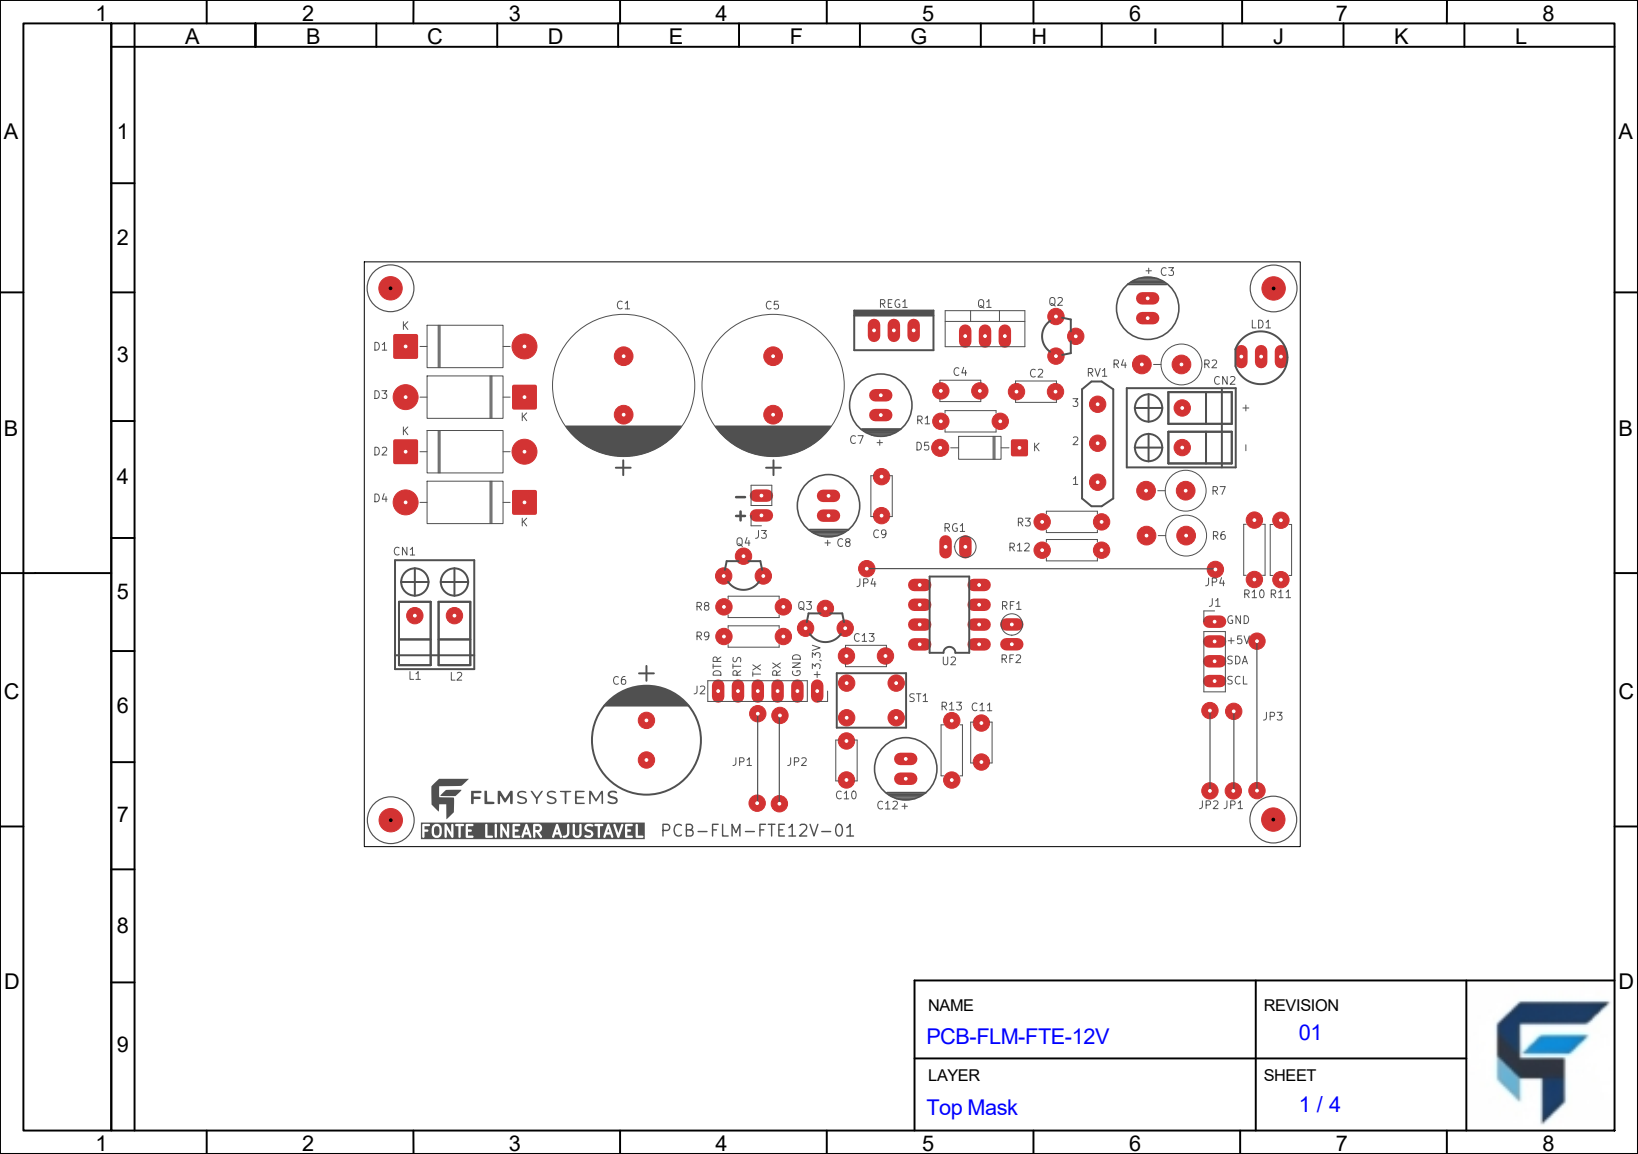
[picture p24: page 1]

SHEET PCB-FLM-FTE-12V

NAME; REVISION; Top Layer; LAYER

SHEET PCB-FLM-FTE-12V

NAME; REVISION; Bottom Mask; LAYER; CBA CBAD; D6 REG3; REG2

SHEET PCB-FLM-FTE-12V

NAME; REVISION; Bottom Layer; LAYER

SHEET PCB-FLM-FTE-12V

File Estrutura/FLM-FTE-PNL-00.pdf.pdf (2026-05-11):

COARSE; FINE; STATUS; POWER SUPPLY

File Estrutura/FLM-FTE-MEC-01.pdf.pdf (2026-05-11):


Dept. | Technical reference | Created by Felipe Canjerano 11/05/2026 | Approved by

Document type | Document status

Title FNT | DWG No.

Rev. | Date of issue | Sheet 1/1

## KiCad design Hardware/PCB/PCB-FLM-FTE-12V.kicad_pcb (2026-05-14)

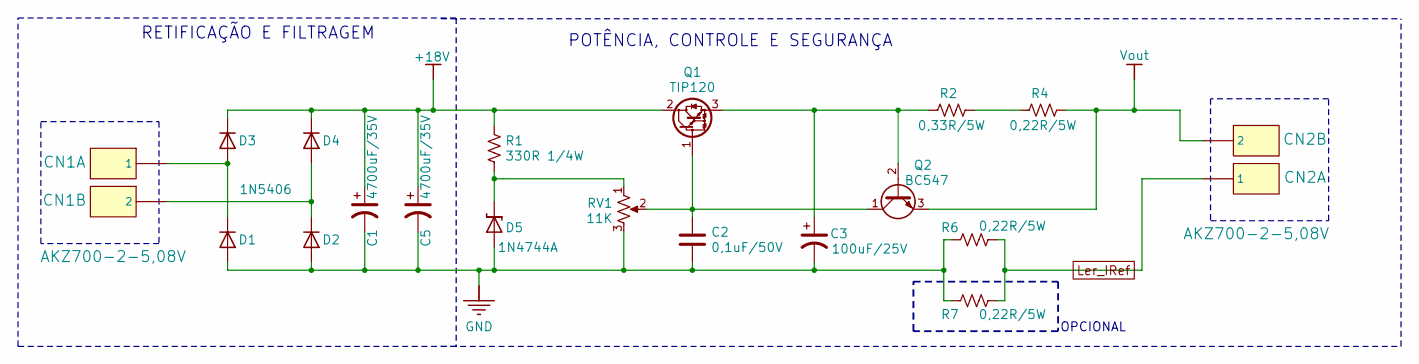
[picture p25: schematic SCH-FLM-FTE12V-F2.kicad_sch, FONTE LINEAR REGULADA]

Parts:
C1, C5: 4700uF/35V; CP_Radial_D18.0mm_P7.50mm
C2: 0,1uF/50V; C_Disc_D5.0mm_W2.5mm_P5.00mm
C3: 100uF/25V; CAP100UF25V
CN1, CN2: AKZ700-2-5,08V; AKZ300-2-5.08
D1, D2, D3, D4: 1N5406; D_DO-201AD_P15.24mm_Horizontal
D5: 1N4744A; D_DO-41_SOD81_P10.16mm_Horizontal
Q1: TIP120; TO-220-3_Vertical
Q2: BC547; TRANSP(CBE)_BC547
R1: 330R 1/4W; R_Axial_DIN0207_L6.3mm_D2.5mm_P7.62mm_Horizontal
R2: 0,33R/5W; R_Axial_DIN0516_L15.5mm_D5.0mm_P5.08mm_Vertical
R4, R6, R7: 0,22R/5W; R_Axial_DIN0516_L15.5mm_D5.0mm_P5.08mm_Vertical
RV1: 11K; POTENCIOMETRO

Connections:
+18V: C1.1, C5.1, D3.1 (K), D4.1 (K), Q1.2 (C), R1.1; also elsewhere on the board
GND: C1.2, C2.2, C3.2, C5.2, D1.2 (A), D2.2 (A), D5.2 (A), R6.2, R7.2, RV1.3; also elsewhere on the board
Ler_IRef: CN2.1, R6.1, R7.1; also elsewhere on the board
unnamed: CN1.1, D1.1 (K), D3.2 (A)
unnamed: CN1.2, D2.1 (K), D4.2 (A)
unnamed: D5.1 (K), R1.2, RV1.1
unnamed: C2.1, Q1.1 (B), Q2.1 (C), RV1.2
unnamed: C3.1, Q1.3 (E), Q2.2 (B), R2.1
unnamed: R2.2, R4.1
Vout: CN2.2, Q2.3 (E), R4.2; also elsewhere on the board

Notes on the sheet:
RETIFICAÇÃO E FILTRAGEM
POTÊNCIA, CONTROLE E SEGURANÇA
OPCIONAL

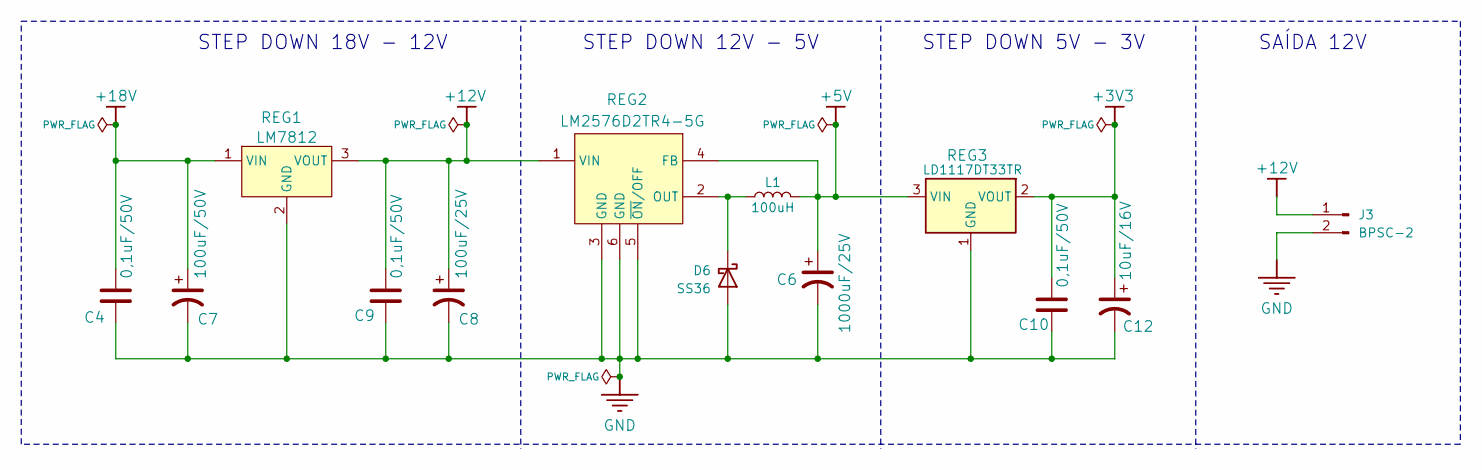
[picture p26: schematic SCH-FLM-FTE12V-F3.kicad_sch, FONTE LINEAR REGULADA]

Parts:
C4, C9, C10: 0,1uF/50V; C_Disc_D5.0mm_W2.5mm_P5.00mm
C6: 1000uF/25V; CAP_1000UF_50V
C7: 100uF/50V; CAP100UF25V
C8: 100uF/25V; CAP100UF25V
C12: 10uF/16V; CAP100UF25V
D6: SS36; DO-214AA_SMB_J-BEND
J3: BPSC-2; PinSocket_1x02_P2.54mm_Vertical
L1: 100uH; 74477120
REG1: LM7812; LM78XX
REG2: LM2576D2TR4-5G; D2PAK-5
REG3: LD1117DT33TR; DPAK_LD1117; Mouser Part Number 511-LD1117DT33-TR

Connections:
+3V3: C10.1, C12.1, REG3.2 (VOUT); also elsewhere on the board
+5V: C6.1, L1.2, REG2.4 (FB), REG3.3 (VIN); also elsewhere on the board
+12V: C8.1, C9.1, J3.1, REG1.3 (VOUT), REG2.1 (VIN); also elsewhere on the board
+18V: C4.1, C7.1, REG1.1 (VIN); also elsewhere on the board
GND: C4.2, C6.2, C7.2, C8.2, C9.2, C10.2, C12.2, D6.2 (A), J3.2, REG1.2 (GND), REG2.3 (GND), REG2.5 (~ON/OFF), REG2.6 (GND), REG3.1 (GND); also elsewhere on the board
unnamed: D6.1 (K), L1.1, REG2.2 (OUT)

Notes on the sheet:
SAÍDA 12V
STEP DOWN 18V - 12V
STEP DOWN 12V - 5V
STEP DOWN 5V - 3V

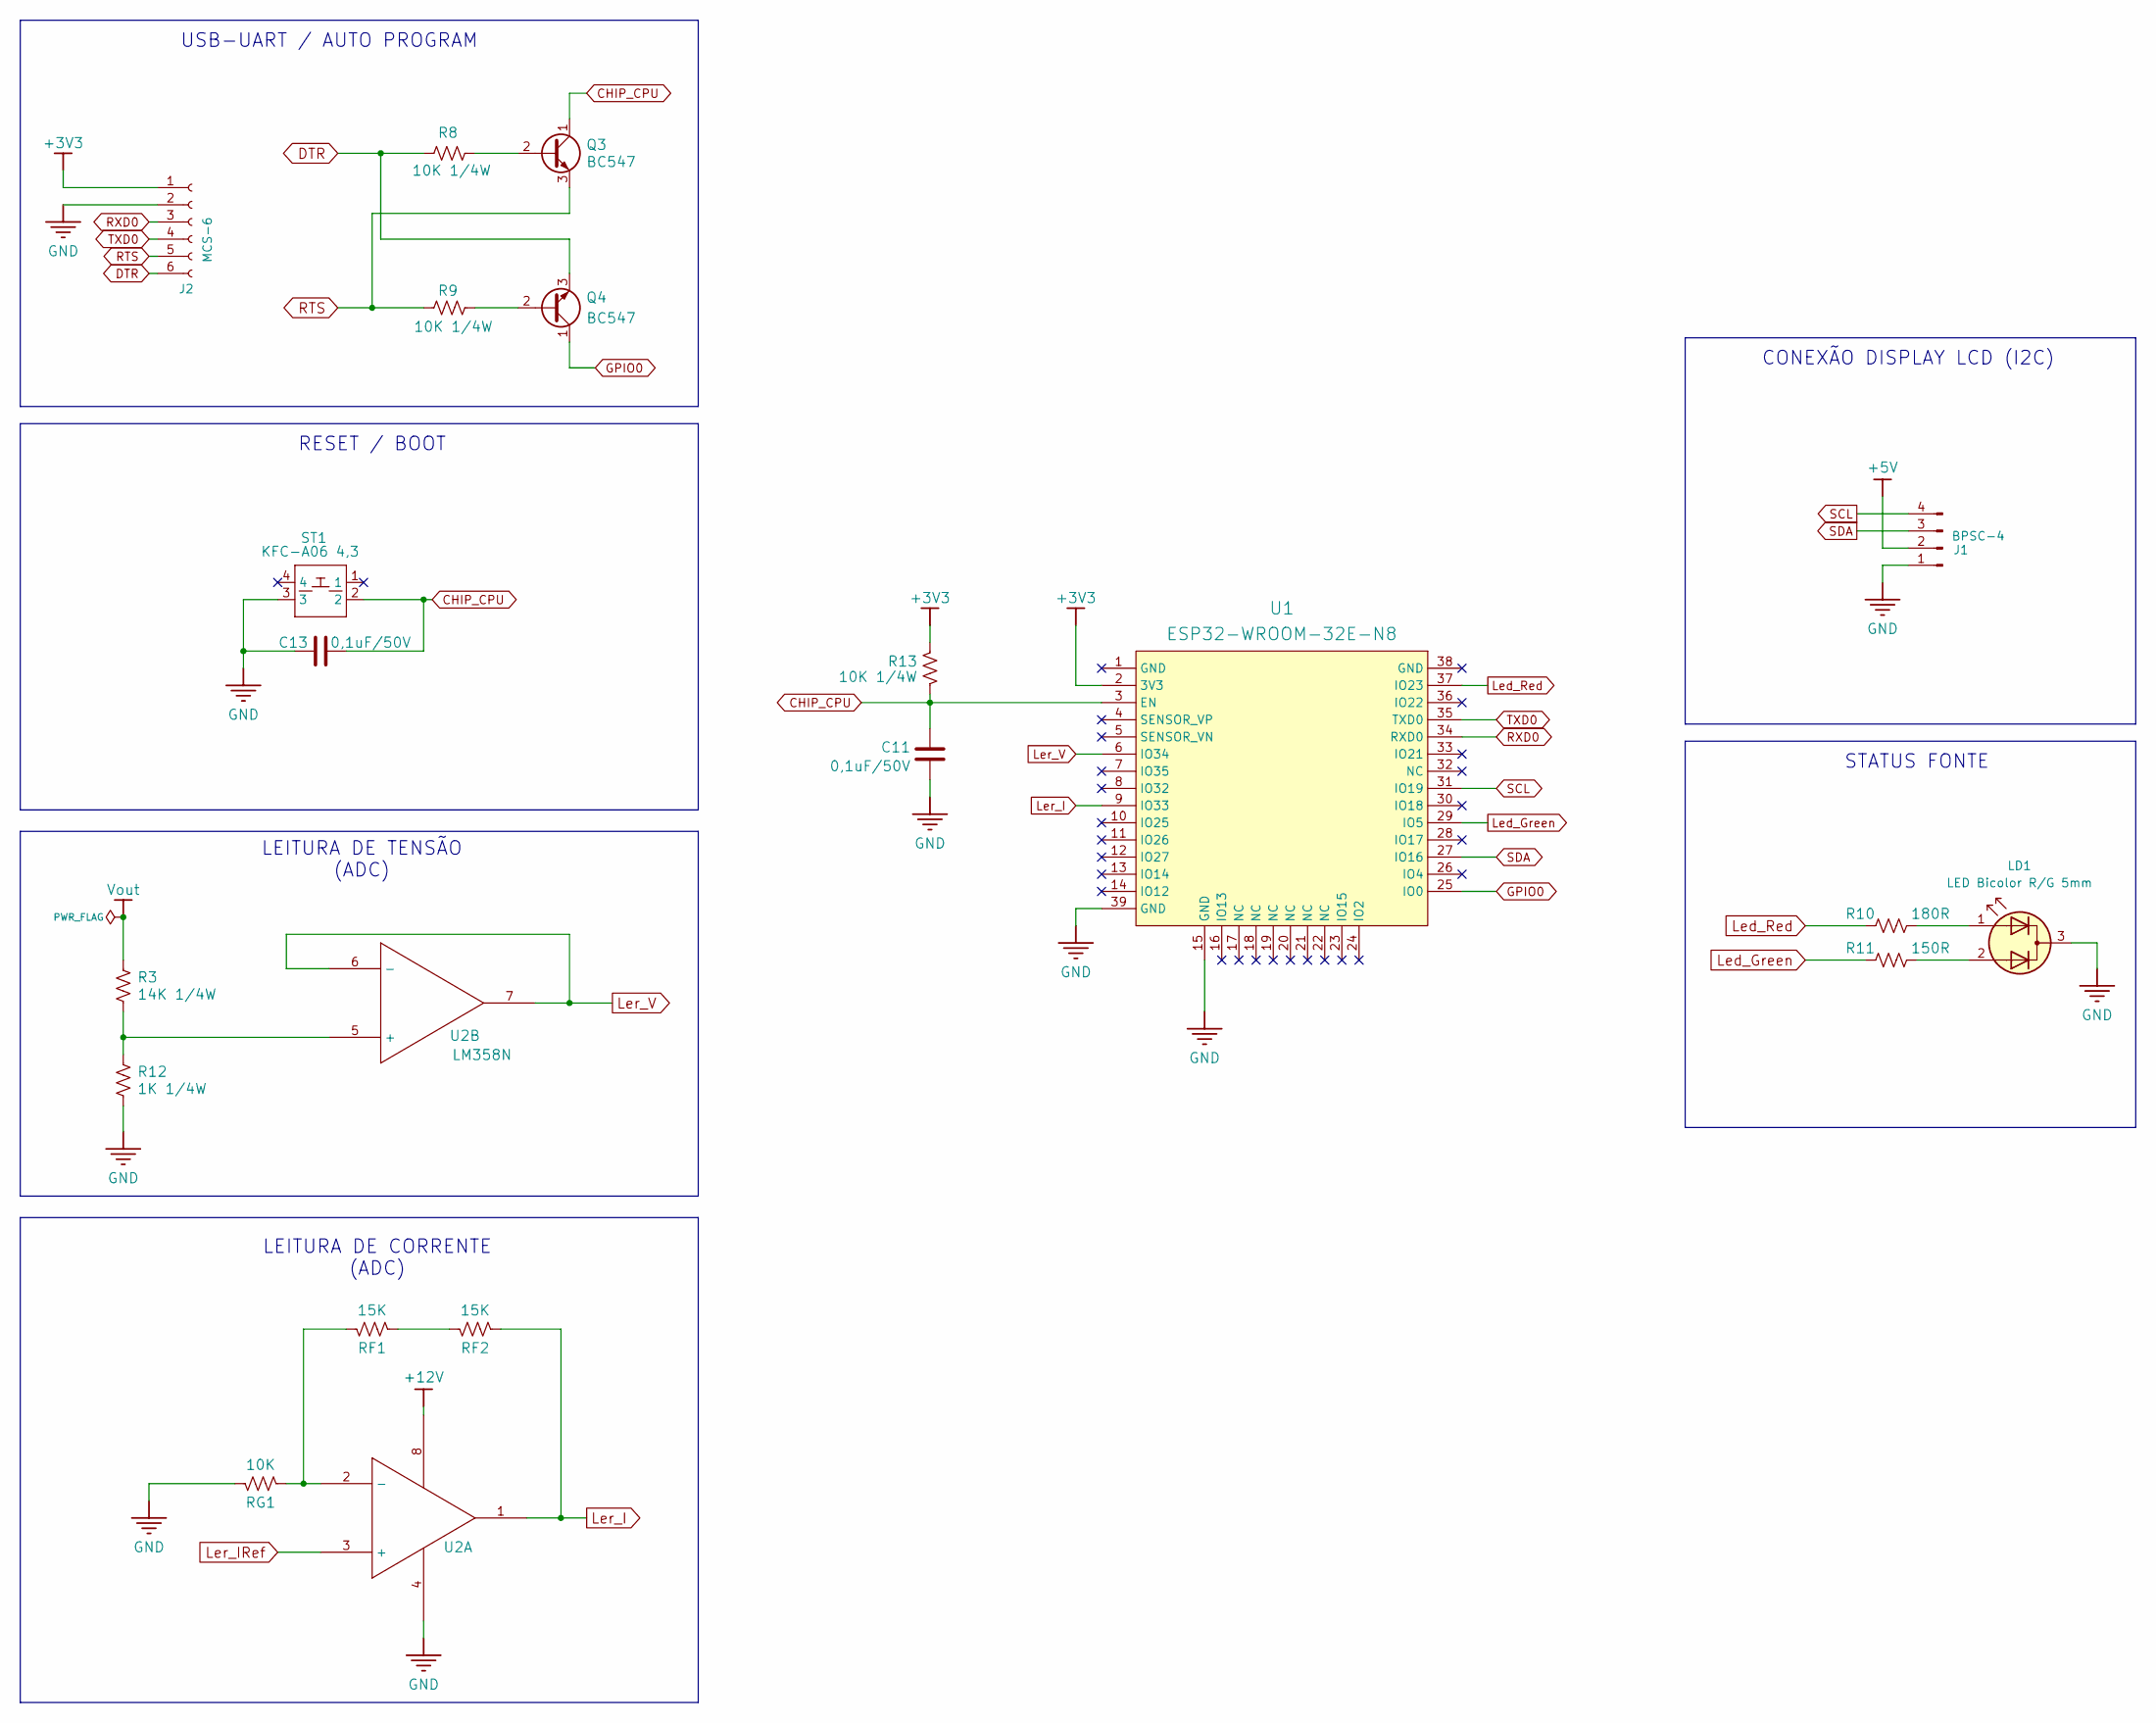
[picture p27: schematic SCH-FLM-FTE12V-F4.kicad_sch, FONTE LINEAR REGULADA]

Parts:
C11, C13: 0,1uF/50V; C_Disc_D5.0mm_W2.5mm_P5.00mm
J1: BPSC-4; PinHeader_1x04_P2.54mm_Vertical
J2: MCS-6; PinSocket_1x06_P2.54mm_Vertical
LD1: LED Bicolor R/G 5mm; LED5MM_BICOLOR_K
Q3, Q4: BC547; TRANSP(CBE)_BC547
R3: 14K 1/4W; R_Axial_DIN0207_L6.3mm_D2.5mm_P7.62mm_Horizontal
R8, R9, R13: 10K 1/4W; R_Axial_DIN0207_L6.3mm_D2.5mm_P7.62mm_Horizontal
R10: 180R; R_Axial_DIN0207_L6.3mm_D2.5mm_P7.62mm_Horizontal
R11: 150R; R_Axial_DIN0207_L6.3mm_D2.5mm_P7.62mm_Horizontal
R12: 1K 1/4W; R_Axial_DIN0207_L6.3mm_D2.5mm_P7.62mm_Horizontal
RF1, RF2: 15K; R_Axial_DIN0207_L6.3mm_D2.5mm_P2.54mm_Vertical
RG1: 10K; R_Axial_DIN0207_L6.3mm_D2.5mm_P2.54mm_Vertical
ST1: KFC-A06 4,3; PUSHBOTON
U1: ESP32-WROOM-32E-N8
U2: LM358N; DIP8

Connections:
+3V3: J2.1, R13.2, U1.2 (3V3); also elsewhere on the board
+5V: J1.2; also elsewhere on the board
+12V: U2.8 (V+); also elsewhere on the board
CHIP_CPU: C11.1, C13.2, Q3.1 (C), R13.1, ST1.2, U1.3 (EN)
DTR: J2.6, Q4.3 (E), R8.1
GND: C11.2, C13.1, J1.1, J2.2, LD1.3 (K), R12.2, RG1.1, ST1.3, U1.15 (GND), U1.39 (GND), U2.4 (GND); also elsewhere on the board
GPIO0: Q4.1 (C), U1.25 (IO0)
Led_Green: R11.1, U1.29 (IO5)
Led_Red: R10.1, U1.37 (IO23)
Ler_I: RF1.2, RF2.1, RF2.2, U1.9 (IO33), U2.1 (OUT)
Ler_IRef: U2.3 (+); also elsewhere on the board
Ler_V: U1.6 (IO34), U2.6 (-), U2.7 (OUT)
unnamed: LD1.1 (A1), R10.2
unnamed: LD1.2 (A2), R11.2
unnamed: Q3.2 (B), R8.2
unnamed: Q4.2 (B), R9.2
unnamed: RF1.1, RG1.2, U2.2 (-)
unnamed: R3.2, R12.1, U2.5 (+)
RTS: J2.5, Q3.3 (E), R9.1
RXD0: J2.3, U1.34 (RXD0)
SCL: J1.4, U1.31 (IO19)
SDA: J1.3, U1.27 (IO16)
TXD0: J2.4, U1.35 (TXD0)
Vout: R3.1; also elsewhere on the board

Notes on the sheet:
STATUS FONTE
RESET / BOOT
USB-UART / AUTO PROGRAM
LEITURA DE CORRENTE (ADC)
LEITURA DE TENSÃO (ADC)
CONEXÃO DISPLAY LCD (I2C)

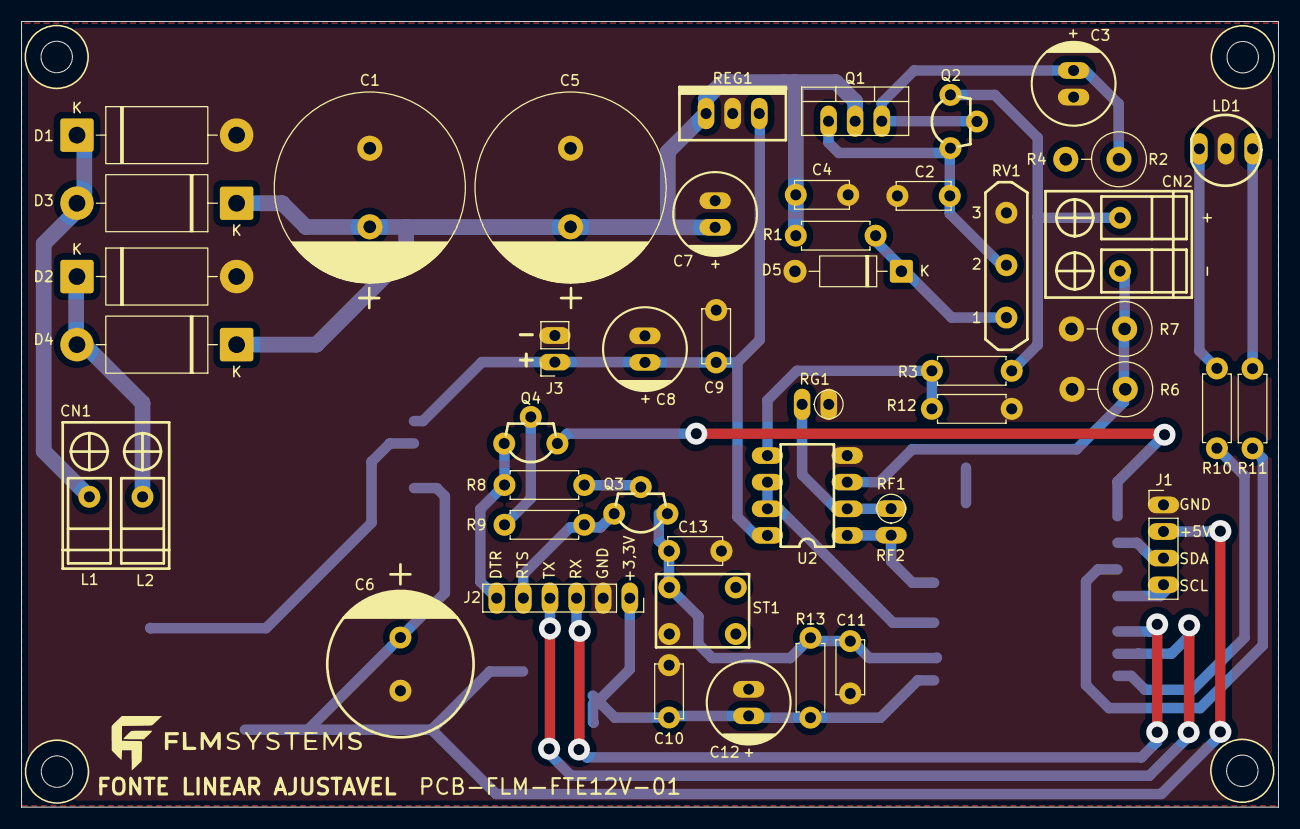
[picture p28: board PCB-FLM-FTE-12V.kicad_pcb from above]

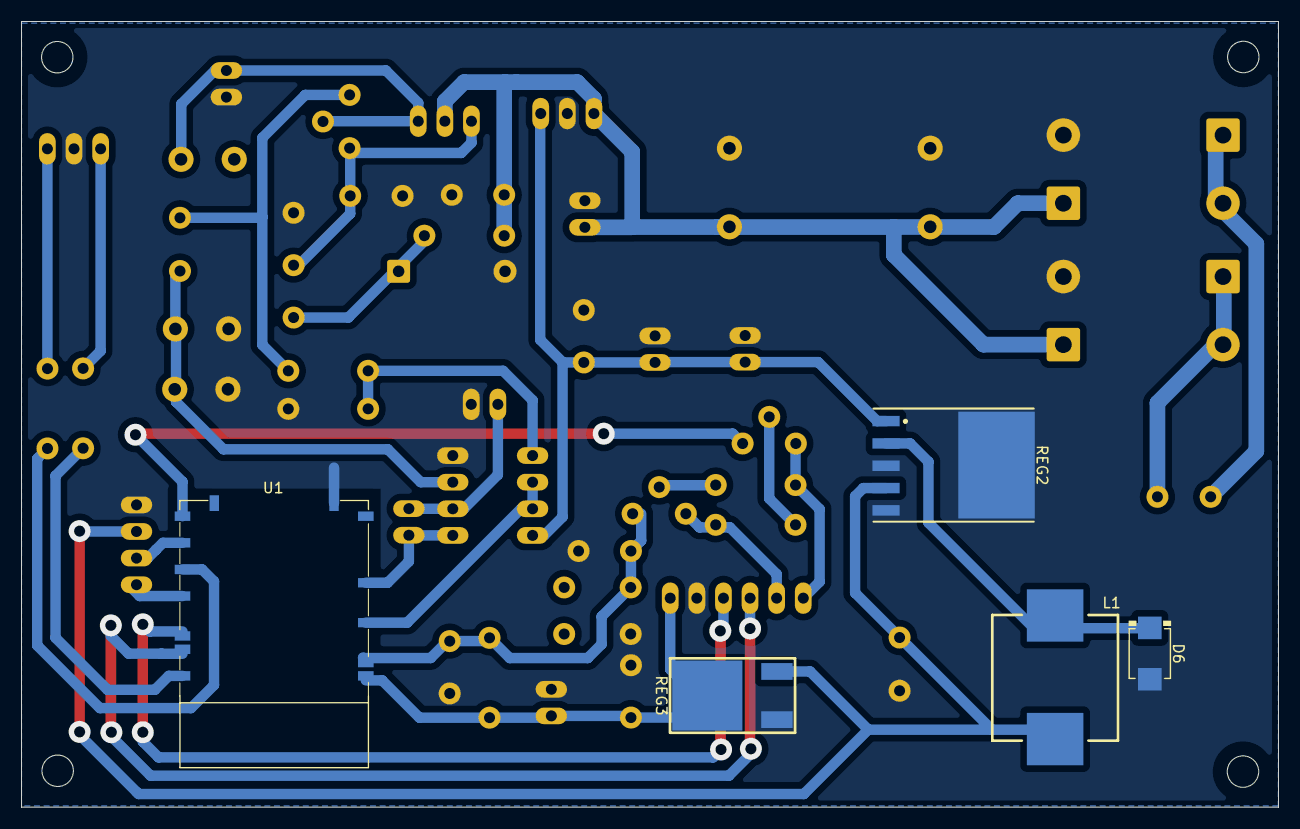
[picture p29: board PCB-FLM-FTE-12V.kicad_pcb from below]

Board: 2 copper layers, 120.0 x 75.0 mm, 54 parts (5 on the bottom side), 31 nets.

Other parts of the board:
Furo11, Furo11#2, Furo11#3, Furo11#4: Furo 3mm

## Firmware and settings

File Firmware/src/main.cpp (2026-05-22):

//=======================================================================================
//	PROJETO     : FONTE LINEAR AJUSTAVEL 12V 1A COM MONITORAMENTO
//	EQUIPE      : FLM SYSTEMS
//	COMPILADOR  : VISUAL STUDIO CODE (1.116.0) + PLATFORMIO
//	PROCESSADOR : ESP32 WROOM 32E
//	DATA        : 15/04/2026
//	REVISAO		  : 22/05/2026
//	VERSÃO      : 0.02.01
//  OBS: Implementação do web server com o esp32, possibilitando a criação do site.
//***************************************************************************************/

// ================ INCLUSÃO DE BIBLIOTECAS ================
  #include <Arduino.h>
  #include <Wire.h>
  #include <LiquidCrystal_I2C.h>
  #include <WiFi.h>
  #include <WebServer.h>

// ================ INCLUSÃO DE FUNÇÕES ================
  #include "html.h"
  #include "images.h"

// ================ CONFIGURAÇÕES DE REDE ================
  const char* ssid = "FLM_FTE12V";
  const char* password = "11110000";

// ================ CONFIGURAÇÕES DO LCD E SERVER ================
  LiquidCrystal_I2C lcd(0x27, 20, 4);
  WebServer server(80);

// ================ DEFINIÇÃO DE PINOS ================
  #define SDA_PIN 16
  #define SCL_PIN 19
  #define PIN_V 34
  #define PIN_I 33
  #define PIN_LDRED 23
  #define PIN_LDGREEN 5

// ================ PARAMETROS ================
  float Vref = 1.1;          // Referência pura do ESP32 (ADC_0db)
  float fator_tensao = 15.0; // Divisor de tensão (14K + 1K) / 1K
  float Rshunt = 0.22;       // Resistor shunt para medição da corrente 
  float ganho_I = 4.0;       // Ganho do AmpOp da corrente 

// ================ CALIBRAÇÃO ================

  // ===== PONTOS DE CALIBRAÇÃO TENSÃO =====
    float V1_real = 3.93;
    float V1_adc  = 3.00;

    float V2_real = 14.26;
    float V2_adc  = 14.39;

    // ===== CALCULO AUTOMATICO =====
      float Va = (V2_real - V1_real) / (V2_adc - V1_adc);
      float Vb = V1_real - Va * V1_adc;

  // ===== PONTOS DE CALIBRAÇÃO CORRENTE =====
    float I1_real = 0.089;
    float I1_adc  = 0.007;

    float I2_real = 1.1;
    float I2_adc  = 1.166;

    // ===== CALCULO =====
      float Ia = (I2_real - I1_real) / (I2_adc - I1_adc);
      float Ib = I1_real - Ia * I1_adc;

// ================ VARIÁVEIS ================
  float tensaoAtual = 0;
  float correnteAtual = 0;
  float potenciaAtual = 0;
  unsigned long tempoAnterior = 0;

// ================ OFFSET CORRENTE ================
  float offsetShunt = 0;

// ================ FILTRO ================
  const int N_AMOSTRAS = 60;

  float lerMedia(int pin) {
    long soma = 0;
    for (int i = 0; i < N_AMOSTRAS; i++) {
      soma += analogRead(pin);
      delayMicroseconds(277); // 277us * 60 =~ 16,6 milissegundos (exatamente 1 ciclo de 60Hz)
    }
    return soma / (float)N_AMOSTRAS;
  }

// ================ MEDIÇÃO DE OFFSET ================
  void medirOffset() {
    float soma = 0;

    for (int i = 0; i < 200; i++) {
      float vadc_I = lerMedia(PIN_I);
      float Vshunt = (vadc_I / 4095.0) * Vref;
      soma += Vshunt;
      delay(5);
    }

    offsetShunt = soma / 200.0;
  }
// ==========================================
//             SETUP INICIAL
// ==========================================
  void setup() {
    Serial.begin(115200);

    // ================ INICIALIZAÇÃO DO LCD ================
      Wire.begin(SDA_PIN, SCL_PIN);
      lcd.init();
      lcd.backlight();

    // ================ CONFIGURAÇÃO DE PINOS ================
      pinMode(PIN_LDRED, OUTPUT);
      pinMode(PIN_LDGREEN, OUTPUT);

    // ================ CONFIGURAÇÃO DO AP ================
      WiFi.mode(WIFI_AP);
      WiFi.softAP(ssid, password);

      IPAddress IP = WiFi.softAPIP();

      Serial.println("AP iniciado");
      Serial.println(IP);

      lcd.clear();
      lcd.setCursor(0,0); lcd.print("WiFi:");
      lcd.setCursor(0,1); lcd.print(ssid);
      lcd.setCursor(0,2); lcd.print("IP:");
      lcd.setCursor(0,3); lcd.print(IP);
      delay(2000);
      lcd.clear();

    // ==========================================
    //         CONFIGURAÇÃO DO SERVIDOR            
    // ==========================================

      // ================ PAGINA PRINCIPAL ================
        server.on("/", []() {
          server.send(200, "text/html", INDEX_HTML);
        });

      // ================ DADOS EM JSON ================
        server.on("/dados", []() {
          String json = "{\"v\":" + String(tensaoAtual,2) +
                        ",\"i\":" + String(correnteAtual,3) +
                        ",\"p\":" + String(potenciaAtual,2) + "}";
          server.send(200, "application/json", json);
        });

      // =============== IMAGENS ================
        server.on("/logo.png", []() {
        server.send_P(200, "image/png", (const char*)FLM_Systems_Logo, FLM_Systems_Logo_len);
        });

        server.on("/fonte.png", []() {
        server.send_P(200, "image/png", (const char*)Fonte_de_Bancada, Fonte_de_Bancada_len);
        });
      
      // ================ INICIALIZAÇÃO DO SERVIDOR ================
        server.begin();

    // ================ CONFIGURAÇÃO DO ADC ================
      analogReadResolution(12);
      analogSetAttenuation(ADC_0db);

    // MEDIR OFFSET COM A FONTE SEM CARGA
      lcd.setCursor(0,0); lcd.print("Calculando OFFSET...");
      medirOffset();
      lcd.clear();
  }


// ==========================================
//             LOOP PRINCIPAL
// ==========================================
  void loop() {

    // ================ MANUTENÇÃO DO SERVIDOR ================
      server.handleClient();

    // ================ LEITURA DE DADOS E ATUALIZAÇÃO DO LCD ================
      if (millis() - tempoAnterior >= 300) {
        tempoAnterior = millis();
      
        // Leitura dos ADCs e cálculo de tensão, corrente e potência
          float vadc_V = lerMedia(PIN_V);
          float vadc_I = lerMedia(PIN_I);

          float Vadc = (vadc_V / 4095.0) * Vref;
          float Vshunt_amplificado = (vadc_I / 4095.0) * Vref;
          
          
          // ===== TRATAMENTO DA CORRENTE =====
          // Subtrair o offset do shunt para obter a corrente real, e evitar que o ruído seja interpretado como corrente
          float Vshunt_sem_offset = Vshunt_amplificado - offsetShunt;
          if (Vshunt_sem_offset < 0) Vshunt_sem_offset = 0; // Evitar valores negativos devido a ruído
          
          // Remover o ganho do amplificador para obter a tensão real no shunt
          float Vshunt_real = Vshunt_sem_offset / ganho_I;
          
          //===== TENSÃO E CORRENTE BRUTA =====
            // Descomente as linhas abaixo para usar os valores sem calibradção, apenas com o fator de escala e offset do shunt
            // tensaoAtual = (Vadc * fator_tensao);
            // correnteAtual = (Vshunt_real / Rshunt);
                
          
          // ===== LEITURAS CALIBRADAS =====
            float tensao = (Va * (Vadc * fator_tensao) + Vb);
            correnteAtual = (Ia * (Vshunt_real / Rshunt) + Ib);

          // ===== REMOÇÃO DA QUEDA DE TENSÃO NO RSHUNT =====
            tensaoAtual = tensao - Vshunt_real;

          // ===== ZERAR RUÍDO DA CORRENTE =====
            if (correnteAtual < 0.090) correnteAtual = 0;

          // ===== POTENCIA =====
            potenciaAtual = tensaoAtual * correnteAtual;

          digitalWrite(PIN_LDGREEN, correnteAtual < 1.1);
          digitalWrite(PIN_LDRED, correnteAtual >= 1.1);

        // ================ ATUALIZAÇÃO DO LCD ================
          lcd.setCursor(0, 0);
          lcd.print("FONTE LINEAR 12V   ");
          lcd.setCursor(0, 1);
          lcd.print("Tensao: ");
          lcd.setCursor(10, 1);
          lcd.print("        ");
          lcd.setCursor(10, 1);
          lcd.print(tensaoAtual, 2);
          lcd.print(" V");
          lcd.setCursor(0, 2);
          lcd.print("Corrente:");
          lcd.setCursor(10, 2);
          lcd.print("          ");
          lcd.setCursor(10, 2);
          lcd.print(correnteAtual, 3);
          lcd.print(" A");
          lcd.setCursor(0, 3);
          lcd.print("Potencia:");
          lcd.setCursor(10, 3);
          lcd.print("        ");
          lcd.setCursor(10, 3);
          lcd.print(potenciaAtual, 2);
          lcd.print("  W");
        }
  }

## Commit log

2026-05-09 Substituição do C1 e C5
    [PCB-FLM-FTE-12V.kicad_pcb]
2026-05-10 Versão 02.00 - Atualização nos arquivos gerbers
    [PCB-FLM-FTE-12V.kicad_pcb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]
2026-05-11 Reorganização de pastas e documentação
    [FLM-FTE-BOM-01.xlsx.xlsx, PCB-FLM-FTE-12V.kicad_pcb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]
2026-05-11 Atualização do resistor shunt R2 e R4
    [SCH-FLM-FTE12V-F2.kicad_sch, SCH-FLM-FTE12V-F3.kicad_sch]
2026-05-11 Atualização do arquivo 'FLM-FTE-SCH-01'
    [FLM-FTE-BOM-01.xlsx, SCH-FLM-FTE12V-F3.kicad_sch]
2026-05-12 Adição do R7 em paralelo com R6 e adição do RF2 de 15K e mudança de valor do RF1 de 10K para 15K
    [PCB-FLM-FTE-12V.kicad_pcb, SCH-FLM-FTE12V-F2.kicad_sch, SCH-FLM-FTE12V-F4.kicad_sch]
2026-05-12 Atualização dos arquivos para fabricação da PCB
    Foi alterado os arquivos gerber e também PDF do esquemático e PCB. Arquivos:
    'FLM-FTE-SCH-01'
    'FLM-FTE-PCB-FAB-01'
    'FLM-FTE-PCB-01'.
    Também foi feito a inclusão Datasheet ESP32
    [PCB-FLM-FTE-12V-Bottom Layer.gbl, PCB-FLM-FTE-12V-Bottom Mask.gbs, PCB-FLM-FTE-12V-Bottom Silkscreen.gbo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]
2026-05-13 Atualização arquivos Gerbers
    [PCB-FLM-FTE-12V.kicad_pcb]
2026-05-13 Inclusão dos arquivos G-Code
    [PCB-FLM-FTE-12V-Bottom Layer.gbl, PCB-FLM-FTE-12V-Bottom Mask.gbs, PCB-FLM-FTE-12V-Bottom Silkscreen.gbo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]
2026-05-13 Inclusão dos arquivos SVG para fabricação a laser
    [PCB-FLM-FTE-12V.kicad_pcb]
2026-05-14 Remoção dos Jumpers no TopSilkscreen
    [PCB-FLM-FTE-12V.kicad_pcb]
2026-05-14 Atualização da senha para acesso ao wifi do esp32 e README.md
2026-05-14 Alteração nos pinos de leitura de Tensão (PIN_V) e Corrente (PIN_I)
2026-05-14 Alteração no 'ganho_I' para 4.0
2026-05-14 Atualização do PDF 'FLM-FTE-PCB-FAB-01'
2026-05-15 Alteração nos arquivos Drilling
2026-05-16 Alteração nos pinos do LED
2026-05-16 Alteração do valor resistor shunt para 0,55ohms
2026-05-16 Alteração resistor shunt
2026-05-16 Alteração no valor maximo e minimo de sobre corrente dos leds
2026-05-22 Atualização dos valores de calibração
2026-05-23 Atualização do esquemático - R7 opcional
    [SCH-FLM-FTE12V-F2.kicad_sch]
2026-05-23 Inclusão do arquivo FLM-FTE-PCB-3D-01
2026-05-24 Alteração no arquivo FLM-FTE-BOM-01
    [FLM-FTE-BOM-01.xlsx]
2026-05-25 Atualização dos dados de calibração
2026-05-28 Inclusção dos datasheet
    [FLM-FTE-BOM-01.xlsx]
2026-05-30 Inclusão dos arquivos de simulação
    [PCB-FLM-FTE-12V-Bottom Layer.gbl, PCB-FLM-FTE-12V-Bottom Mask.gbs, PCB-FLM-FTE-12V-Bottom Silkscreen.gbo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]
